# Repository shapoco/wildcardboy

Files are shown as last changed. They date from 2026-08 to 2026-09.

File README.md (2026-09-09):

# [WIP] WildCardBoy

Handheld Game Console with Replaceable MCU

## Concept

WildCardBoy is a handheld game console whose "brain" (MCU) can be swapped out.
It consists of two units:

- **Host shell**: The main unit with an LCD, keypad, TF card slot, and power supply.
  It has no game-execution capability of its own; instead, it has a slot for a logic card on its back.
- **Logic card**: A daughterboard that plugs into the slot. It carries the MCU that runs the game,
  along with the CPU peripheral circuitry of the target game console (e.g. TinyJoypad, Arduboy).

The differences between game consoles are confined to the logic card,
so supporting a new game console only requires building a new logic card.

The host shell acts as an RP2350B-based host controller with the following roles:

- Detecting the logic card and identifying its type via the on-card EEPROM (card profile)
- Reading keypad input and sending it to the logic card
- Driving the LCD based on drawing commands received from the logic card
- Flashing game programs stored on the TF card to the MCU on the logic card

For detailed specifications, see [spec/](spec/).

For demos and the latest development status, see the [#WildCardBoy tag on X](https://x.com/hashtag/WildCardBoy?f=live).

## Schematics

[host_shell.kicad_sch](https://kicanvas.org/?repo=https://github.com/shapoco/wildcardboy/blob/main/kicad/host_shell.kicad_sch)

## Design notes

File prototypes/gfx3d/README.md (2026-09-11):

# gfx3d プロトタイプ

WildCardBoy のシステムメニュー背景用 3D レンダリングライブラリのプロトタイプ。
仕様は [SPEC.md](SPEC.md) を参照。

## ディレクトリ構成

- `lib/include/shapoco/gfx3d/`: 公開ヘッダ (`gfx3d.hpp`, `math3d.hpp`)
- `lib/src/`: ライブラリ実装
- `example/common/`: サンプル共通のデモシーン (`scene.cpp`)
- `example/wasm/`: ブラウザ動作確認用サンプルの WASM ビルド環境
- `example/pretest/`: 実機 (pretest 試作機) での性能確認用ファームウェア。詳細は [example/pretest/README.md](example/pretest/README.md)
- `../../docs/prototypes/gfx3d/`: ビューアページ (index.html, main.js, gfx3d.wasm)

## ビルドと実行

Emscripten (emcc) が必要。

```sh
cd prototypes/gfx3d/example/wasm
make          # docs/prototypes/gfx3d/gfx3d.wasm を生成
make serve    # docs/ をルートに HTTP サーバを起動
```

ブラウザで http://localhost:8000/prototypes/gfx3d/ を開く。
(fetch を使用するため file:// では動作しない)

## コンパイルオプション

- `GFX3D_PERSPECTIVE_CORRECT_UV=1`: テクスチャ座標の透視補正を有効にする
  (デフォルトはアフィン補間。ピクセル単位の除算が追加される)

## メモリ使用量の目安

作業メモリはすべて `init()` に渡したアリーナから確保される。
サンプルは 128KB のアリーナを使用しており、内訳の目安は以下のとおり
(32bit 環境、`lib/src/gfx3d.cpp` の内部構造体のサイズに依存):

- ラインバケット: 画面の高さ x 4 バイト
- 線分プール: 残りの 1/4 (上限 512 個、1 個 64 バイト)
- トライアングルバッファ: 残り全部 (1 三角形約 124 バイト + インデックス 4 バイト。128KB のアリーナで約 770 個)

バッファがあふれた場合、超過分の三角形/線分はそのフレームでは破棄される。

## 制約

- テクスチャの幅・高さは 2 の冪であること (ラップをビットマスクで行うため。そうでない場合は繰り返しがずれる)
- ピクセル処理は固定小数点で、色は切り捨てで RGB565 に量子化される (float 実装との差は概ね 1 LSB 以内)

## 参考性能

480x320 のサンプルシーン (トーラス + キューブ 4 個、半透明・テクスチャ・環境マップ込み) を 1 フレーム:

- WASM (Node.js, シングルスレッド): 約 3 ms (固定小数化前は約 8 ms)
- RP2350 (312 MHz, シングルコア, `example/pretest`): 固定小数化前は render 約 55 ms (15〜18 fps)

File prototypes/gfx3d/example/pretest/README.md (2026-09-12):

# gfx3d pretest 実機サンプル

gfx3d プロトタイプの性能を実機で確認するためのファームウェア。
WASM サンプルと同じシーン ([../common/scene.cpp](../common/scene.cpp)) をホストシェルの LCD に描画する。

対象は **pretest の試作機** (ピン配置は [pretest/include/board_pins.hpp](../../../../pretest/include/board_pins.hpp) に従い、
[spec/](../../../../spec/) のピンアサインとは異なる)。ロジックカードは使用しない (LCIO / LCAUX / TF カードは触らない)。

## 構成

- pretest の足回りを無改造で流用: `board_pins.hpp` (ピン定義)、`sys_clock.cpp` (312 MHz)、
  `aux_i2c.cpp` (HAUX の PCA9555 キーパッド)、`lcd8080.pio` (8080 8bit 出力)
- `src/lcd_ili9488.cpp`: pretest の `ili9488.cpp` を元に、帯単位の非同期 DMA 転送 (`writeBytesAsync()`) を追加した LCD ドライバ
- `src/overlay.cpp`: 帯バッファへの文字描画 (LcdTap の 8x16 フォントをヘッダのみで使用)
- `src/main.cpp`: 描画ループ・計測・カメラ操作
- 全体を SRAM で実行する (`copy_to_ram`)。XIP キャッシュミスで計測値がぶれないようにするため

## 描画方式

480x320 を 32 ラインの帯 10 本に分けて `render()` する。帯バッファは 2 面 (各 30 KB) で、
帯 i を描画している間に帯 i-1 を DMA で LCD へ転送する (40 ns/byte、全画面で約 12.3 ms)。
LCD の TE 信号は試作機では MCU に接続されていないため、ティアリングは発生する。

## ビルド

Pico SDK 2.x と arm-none-eabi-gcc が必要。LcdTap サブモジュール (`submodule/lcdtap`) をチェックアウトしておくこと。
USB CDC 出力には SDK 側の TinyUSB サブモジュール (`$PICO_SDK_PATH/lib/tinyusb`) が必要
(無い場合は CMake が警告を出し、計測値は画面表示のみになる)。

```sh
./build.sh                                    # build/gfx3d_pretest.uf2
./build.sh -DGFX3D_PERSPECTIVE_CORRECT_UV=ON  # テクスチャ座標の透視補正を有効にする
./build.sh -DGFX3D_PERSPECTIVE_CORRECT_UV=OFF # 元に戻す (CMake キャッシュに残るため明示が必要)
```

## 操作

| キー | 動作 |
|---|---|
| 十字キー | カメラ回転 (左右 = yaw、上下 = pitch) |
| A / B | ズームイン / ズームアウト |
| X | カメラを初期位置に戻す |
| START | アニメーションの一時停止 / 再開 |
| SELECT | 画面左上の計測値表示の ON / OFF |

## 計測値

1 秒ごとに USB CDC (本体基板の native USB) へ以下を出力し、画面左上にも表示する。値は 1 フレームあたりの平均 (ms)。

```
[gfx3d] fps=... frame=...ms (max ...) key=... scene=... sort=... render=... (band max ...) swap=... lcdwait=... | cam ...
```

| 項目 | 内容 |
|---|---|
| `key` | キーパッド読み取り (I2C) |
| `scene` | `sceneBuild()` (座標変換・ライティング・投影、`beginScene()` 〜 `endScene()`) |
| `sort` | `beginRender()` (三角形の深度ソート) |
| `render` | 全帯の `render()` 合計。`band max` は 1 帯あたりの最大 |
| `swap` | 計測値の文字描画 + バイトスワップ |
| `lcdwait` | 前の帯の DMA 完了待ち + ウィンドウ設定 (描画が転送より速いと増える) |
| `tri` | 三角形数 (カリング後) / トライアングルバッファの容量。`drop` はあふれて破棄した数 |
| `span` | 1 ラインで同時に使用した線分数の最大 / 線分プールの容量。`drop` はあふれて破棄した数 |
| `arena` | 直近のフレームで実際に使用したアリーナのバイト数 (ラインバケット + 三角形 + 線分のピーク) / アリーナのサイズ |

画面の 3 行目は `tri` / `span` / `arena` (使用率 %) で、あふれが起きたときは数値の後ろに `!` が付く。

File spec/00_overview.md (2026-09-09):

# 概要

## コンセプト

MCU を差し替えることができるハンドヘルドゲームコンソール。
本体側のユニットを「ホストシェル」(host shell)、差し替え可能な子基板を「ロジックカード」(logic card) と呼ぶ。

- ホストシェルには ILI9488 互換 LCD とキーパッド (方向キー、ABXYボタンなど) を搭載。
- ホストシェルにはゲーム自体の実行機能は無く、背面にロジックカードを差し込むスロットがある。
- ロジックカードには頭脳となる MCU が搭載されており、ゲームプログラムはそこで実行される。
- ロジックカードには例えば Tinyjoypad や Arduboy のようなゲーム機の CPU 周辺回路が搭載される。
- 新しいゲーム機に対応するときは、ロジックカードだけを作ればよい。
- ホストシェルには TF カードスロットが搭載され、そこに格納されたゲームプログラムをロジックカード上の MCU に書き込むことができる。

## ホストシェル機能

ホストシェルは RP2350B をコアとして、システム全体を制御する「ホストコントローラ」を構成する。

- ロジックカードの検出
- PCA9555 を経由したキーパッド入力の取得
- ロジックカードへのキーパッド入力状態の送信
- ロジックカードからの LCD 描画命令の受信
- LCD 制御
- TF カード上のファイルシステムのブラウズ
- TF カードからバイナリファイルを読み込んでロジックカード上の MCU へのプログラム書き込み (SPI or USB)

## 回路図

[host_shell.kicad_sch](https://kicanvas.org/?repo=https://github.com/shapoco/wildcardboy/blob/main/kicad/host_shell.kicad_sch)

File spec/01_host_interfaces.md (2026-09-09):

# ホストシェルインタフェース

> **信号名について**: 回路図 (kicad/host_shell.kicad_sch) のネット名では、ホストシェル固有の信号に
> `HS` プレフィックスが付く (例: `HSLCD_D0`、`HSAUX_SDA`、`HSTF_CSX`)。本仕様書では従来どおり
> `H` プレフィックスで表記する。このほか回路図では、負論理信号に `X` サフィックスが付き (例: `HSLCD_RSTX`/`RDX`/`WRX`/`CSX`)、キー入力は `BTN_*` (例: `HKEY_L` → `BTN_L`)、TF カードと共有する SPI バスは `HSSPI_*` (`HTF_MISO/SCK/MOSI` → `HSSPI_MISO/SCK/MOSI`、`HTF_CS` → `HSTF_CSX`) と表記される。また `LCTF_ENAX` は回路図上では `LCTF_ENX` と表記される。

## キーパッド

ボタン類は全て PCA9555 (devaddr=0x21) 経由で読み取られる (電源ボタンを除く。後述「電源I/F」)。
Home ボタンはホストシェル側の機能の呼び出しに使用する。

|GPIO|割り当て|説明|
|---|---|---|
|GPIO36|HAUX_SDA|I2C データライン|
|GPIO37|HAUX_SCL|I2C クロックライン|

|PCA9555ポート|割り当て|説明|
|---|---|---|
|P0_0|HKEY_L|左キー|
|P0_1|HKEY_R|右キー|
|P0_2|HKEY_U|上キー|
|P0_3|HKEY_D|下キー|
|P0_4|HKEY_A|Aボタン|
|P0_5|HKEY_B|Bボタン|
|P0_6|HKEY_X|Xボタン|
|P0_7|HKEY_Y|Yボタン|
|P1_0|HKEY_SEL|SELECTボタン|
|P1_1|HKEY_STA|STARTボタン|
|P1_2|HKEY_BL|Lバンパー|
|P1_3|HKEY_BR|Rバンパー|
|P1_4|HKEY_HOME|Homeボタン|

PCA9555 の残りのポートは制御出力として使用する。

|PCA9555ポート|割り当て|説明|
|---|---|---|
|P1_5|EXTVIDENX|外部ビデオ回路イネーブル (負論理)|
|P1_6|LCVSYSEN|LCVSYS 給電イネーブル (High=給電)|
|P1_7|HLCD_SPIEN|LCD SPI モード切替 (High=SPI)|

- PCA9555 の全ポートは内部プルアップ (約 100kΩ) を持つため、電源投入直後 (全ポート入力状態) の
  上記制御信号は High 相当となる。
- HKEY_D (下キー) は 1kΩ + ショットキーダイオードを介して RP2350B の QSPI_SS にも接続されており、
  下キーを押しながら電源投入 / リセットすると USB ブートモード (BOOTSEL) に入る。
- HKEY_BL / HKEY_BR は基板外実装のスイッチ用コネクタ (J2/J3) に接続される。
- HAUX (GPIO36/37) と LCAUX (GPIO28/29) はどちらも RP2350B の I2C0 にのみ割り当て可能なため、
  ファームウェアはピン機能を切り替えて時分割で使用する。
- HAUX バスには PCA9555 (0x21) のほか RTC (RV-3028-C7、0x52) が接続される (後述「RTC」)。

## LCD I/F

ILI9488 互換の 320x480 ドットの液晶を横に倒して使用する。通常は 8bit パラレル (8080) 接続。
D0-7 は HSTX 対応端子 (GPIO12-19) に割り当てており、将来的に外付け回路による DVI-D / NTSC
出力を試せるよう外部コネクタ (J5) にも引き出している (後述「外部ビデオ出力」)。

|GPIO|割り当て|説明|
|---|---|---|
|GPIO12-19|HLCD_D0-D7|データバス (HSTX 対応端子)|
|GPIO20|HLCD_DC|SPI モードではマルチプレクサでパネルから切り離される|
|GPIO23|HLCD_RST||
|GPIO24|HLCD_RD||
|GPIO25|HLCD_WR|SPI モード (4 線) では D/C として使用|
|GPIO26|HLCD_CS||
|GPIO27|HLCD_VSYNC|パネルの TE 出力 (ホスト側は入力)|
|GPIO46|HLCD_BL|バックライト PWM (High=点灯)|

### SPI モード

HLCD_SPIEN (PCA9555 P1_7) を High にするとパネルのインタフェースストラップが SPI に切り替わり、
パネルの DC/SCL 端子にはアナログマルチプレクサ (SN74LVC1G3157) 経由で HTF_SCK (GPIO34) が
接続される。シリアルデータは HTF_MOSI (GPIO35)。すなわち TF カードと SPI バスを共有する
(CS は HLCD_CS で独立)。4 線 SPI の D/C にはパネルの WR 端子 (HLCD_WR) を使用する。
パネルの SDO は接続していない (書き込み専用)。
HLCD_SPIEN 切り替え後は HLCD_RST でパネルをリセットすること。
D0-7 を外部ビデオ回路が使用している間、本体 LCD はこのモードで制御する。

### 外部ビデオ出力

HLCD_D0-7、HLCD_DC/RST/RD/WR/CS、VSYS、3.3V を外部コネクタ (J5) に引き出している。
EXTVIDENX (PCA9555 P1_5、負論理) で外部回路をイネーブルする。
DVI-D 出力時は D0-7 (HSTX) を 4 差動ペアとして使用する想定 (信号は外部回路側でバッファする)。

## TF カード I/F

SPI 接続。

|GPIO|割り当て|説明|
|---|---|---|
|GPIO32|HTF_MISO||
|GPIO33|HTF_CS||
|GPIO34|HTF_SCK||
|GPIO35|HTF_MOSI||
|GPIO42|HTF_DETX|カード検出。Low=挿入 (基板上でプルアップ)|

- MISO/SCK/MOSI は LCD の SPI モードとバスを共有する (CS は別)。
- ロジックカードへの接続切り替え (LCTF_ENAX) は [02_wildcardbus.md](02_wildcardbus.md) を参照。

## オーディオ I/F

|GPIO|割り当て|説明|
|---|---|---|
|GPIO44|HAUDIO_L|PWM オーディオ出力 (左)|
|GPIO45|HAUDIO_R|PWM オーディオ出力 (右)|

- PWM 出力はシュミットトリガバッファで整形後、RC フィルタ (fc ≈ 7kHz) で平滑され、
  ロジックカードのオーディオ (LCAUDIO_L/R) と抵抗ミックスされる。
- ミックス後の信号は音量ボリュームを経てスピーカアンプ (LM4890 BTL x2) と
  ヘッドホンアンプ (LM4880) に入る。ヘッドホンジャックの挿入検出により
  スピーカ / ヘッドホンはハードウェアで自動的に切り替わる (GPIO 制御不要)。

## 電源I/F

電源系統: VBUS (USB) と VBAT (Li-Po) をダイオード OR した電源を、電源ボタン付きロードスイッチ
(XC6194) を通して VSYS とし、昇降圧 DCDC (TPS63802) で 3.3V を生成する。
充電は MCP73831 (約 370mA)。
電源ボタンのクリックは GPIO41 (BTN_PWRX) で検知し、ファームウェアが後始末をしてから
SYSSD で自己遮断する (安全なシャットダウン)。長押しは XC6194 のハードウェア機能による
強制電源断で、ファームウェアが暴走していても機能する。

|GPIO|信号名|説明|
|---|---|---|
|GPIO39|SYSSD|High でシステム電源断 (XC6194 SHDN)|
|GPIO41 (ADC1)|BTN_PWRX|電源ボタン検知 (Low=押下)。3.3V に 100kΩ でプルアップし、ショットキーダイオード経由で BTN_PWRX ノード (VCOM 系、最大約 4.2V) から絶縁|
|GPIO43 (ADC3)|ADCBAT|バッテリー電圧監視 (VBAT の 1/2 分圧。システム OFF 中は分圧回路ごと切り離される)|

- 電源ボタンで電源 ON した直後はボタンが押されたままのため BTN_PWRX は Low で起動する。
  ファームウェアは一度 High (離した状態) を確認してからクリック検知を有効にすること。
  チャタリング除去もソフトウェアで行う (BTN_PWRX ノードにコンデンサはない)。

ロジックカードへの電源供給:

|電源|制御|説明|
|---|---|---|
|LC3V3|なし|ホストシェル動作中は常時給電|
|LCVSYS|LCVSYSEN (PCA9555 P1_6)|High で給電。ソフトスタート付き|

## RTC

RV-3028-C7 (I2C devaddr=0x52) を HAUX バス (GPIO36/37) に接続している。

|項目|内容|
|---|---|
|VDD|3.3V|
|VBACKUP|VBAT (ヒューズ F2 の下流)。システム OFF 中もバッテリーから時刻保持 (約 45nA)|
|INT|未使用 (テストポイントのみ)。アラームフラグは I2C ポーリングで読む|
|CLKOUT|未使用 (テストポイントのみ)|
|EVI|10kΩ プルダウン (未使用)|

ファームウェアでの初期化時の注意:

- バックアップ切替 (BSM) は POR デフォルトで無効。EEPROM 設定で DSM または LSM を
  一度書き込むこと (EEPROM 保持のため以後は不要)。
- トリクル充電は無効のまま使用する (VBACKUP が Li-Po 直結のため)。
- CLKOUT はデフォルトで 32.768kHz を常時出力するため、無効化して消費電流と輻射を抑える。
- devaddr 0x52 は Xiamocon カードのバッテリー監視 ADC (ADC101C027) と同値だが、
  あちらはカード側バス ([04_host_controller.md](04_host_controller.md) 参照) 上の
  エミュレーションであり、バスが異なるため衝突しない。

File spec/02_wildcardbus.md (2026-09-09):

# ロジックカード I/F (WildCardBus)

2x12 ピンのピンソケット。

|ヘッダピン番号|GPIO|信号名|説明|
|---|---|---|---|
|1|-|LCAUDIO_L|オーディオ左チャンネル|
|2|-|LCAUDIO_R|オーディオ右チャンネル|
|3|-|GND|グランド|
|4|GPIO40 (ADC0)|LCA0|アナログ入力 (ホストシェルの ADC に接続)|
|5|GPIO0|LCIO0|ロジックカード側の GPIO0|
|6|GPIO1|LCIO1|ロジックカード側の GPIO1|
|7|GPIO2|LCIO2|ロジックカード側の GPIO2|
|8|GPIO3|LCIO3|ロジックカード側の GPIO3|
|9|GPIO4|LCIO4|ロジックカード側の GPIO4|
|10|GPIO5|LCIO5|ロジックカード側の GPIO5|
|11|GPIO6|LCIO6|ロジックカード側の GPIO6|
|12|GPIO7|LCIO7|ロジックカード側の GPIO7|
|13|GPIO8|LCIO8|ロジックカード側の GPIO8|
|14|GPIO9|LCIO9|ロジックカード側の GPIO9|
|15|GPIO10|LCIO10|ロジックカード側の GPIO10|
|16|GPIO11|LCIO11|ロジックカード側の GPIO11|
|17|GPIO21|LCIO12|ロジックカード側の GPIO12|
|18|GPIO22|LCIO13|ロジックカード側の GPIO13|
|19|GPIO28|LCAUX_SDA|I2C データライン|
|20|GPIO29|LCAUX_SCL|I2C クロックライン|
|21|GPIO30|LCUSB_DP|USB D+|
|22|GPIO31|LCUSB_DM|USB D-|
|23|-|LC3V3|3.3V 電源 (常時給電)|
|24|-|LCVSYS|VBUS/VBAT の OR 電源 (スイッチ付き)|

- GPIO 列はホストシェル (RP2350B) 側の GPIO 番号。LCIO12/13 は HSTX 端子確保のため
  ホスト側 GPIO21/22 に割り当てられている (信号名・機能は従来どおり)。
- LC3V3 はホストシェル動作中は常時給電される (イネーブル制御なし)。
- LCVSYS は VBUS と VBAT のダイオード OR 出力 (約 3.0〜5.0V) で、ホストシェルが給電を
  ON/OFF する (ソフトスタート付き)。安定した 5V を必要とするカードはカード側で昇圧すること。

## LCD I/F が I2C の場合

|信号名|割り当て|
|---|---|
|LCIO2|LCLCD_SDA|
|LCIO3|LCLCD_SCL|

## LCD I/F が SPI の場合

|信号名|割り当て|
|---|---|
|LCIO0|LCLCD_RST|
|LCIO1|LCLCD_CS|
|LCIO2|LCLCD_SCK|
|LCIO3|LCLCD_MOSI|
|LCIO4|LCLCD_DC|

## LCD I/F が 8bit パラレルの場合

|信号名|割り当て|
|---|---|
|LCIO0|LCLCD_RST|
|LCIO1|LCLCD_CS|
|LCIO2|LCLCD_WR|
|LCIO3|LCLCD_D0|
|LCIO4|LCLCD_D1|
|LCIO5|LCLCD_D2|
|LCIO6|LCLCD_D3|
|LCIO7|LCLCD_D4|
|LCIO8|LCLCD_D5|
|LCIO9|LCLCD_D6|
|LCIO10|LCLCD_D7|
|LCIO11|LCLCD_DC|

## LCD VSYNC 出力

ロジックカード上の MCU が LCD からの同期信号 (ST7789 の TE 信号など) の入力を要求する場合は、
ホストシェルが生成する自走パルスをロジックカードへ供給する (物理 LCD とは同期しない。
[04_host_controller.md](04_host_controller.md))。
割り当ては固定ではなく、カードプロファイルで機能番号 3 のポートとして空いている任意の LCIO に
割り当てる ([03_card_profile.md](03_card_profile.md))。LCD I/F が SPI のカードでは LCIO5 を推奨する。

## キーパッド I/F がパラレルの場合

ロジックカード側の LCD I/F がパラレル以外の場合で、TF カード I/F を持たず、使用するキーが方向キーと A、B、START、SELECT のみの場合は、キーパッド I/F はパラレル接続となる。

|信号名|割り当て|説明|
|---|---|---|
|LCIO5|LCKEY_L|左キー|
|LCIO6|LCKEY_R|右キー|
|LCIO7|LCKEY_U|上キー|
|LCIO8|LCKEY_D|下キー|
|LCIO9|LCKEY_A|Aボタン|
|LCIO10|LCKEY_B|Bボタン|
|LCIO11|LCKEY_STA|STARTボタン|
|LCIO12|LCKEY_SEL|SELECTボタン|

## キーパッド I/F が I2C の場合

キーパッド I/F がパラレルで使用できない場合は I2C 接続となる。I2C は LCAUX_SDA/LCAUX_SCL を通じてロジックカード上の PCA9555 (devaddr=0x20) に接続される。

|PCA9555ポート|割り当て|説明|
|---|---|---|
|P0_0|LCKEY_L|左キー|
|P0_1|LCKEY_R|右キー|
|P0_2|LCKEY_U|上キー|
|P0_3|LCKEY_D|下キー|
|P0_4|LCKEY_A|Aボタン|
|P0_5|LCKEY_B|Bボタン|
|P0_6|LCKEY_X|Xボタン|
|P0_7|LCKEY_Y|Yボタン|
|P1_0|LCKEY_STA|STARTボタン|
|P1_1|LCKEY_SEL|SELECTボタン|
|P1_2|LCKEY_BL|Lバンパー|
|P1_3|LCKEY_BR|Rバンパー|

## キーパッド I/F が仮想 I/O エキスパンダの場合

カードプロファイルの `lcio.useVirtIoExp` が true の場合、ホストコントローラ自身が I2C スレーブとなり、
ロジックカード上の I/O エキスパンダ IC の動作を模擬する (詳細は [03_card_profile.md](03_card_profile.md) および [04_host_controller.md](04_host_controller.md))。
ロジックカード上の MCU は、実チップに対するのと同様に I2C マスタとしてホストへアクセスする。
キーパッド状態のほか、カードによってはディスプレイリセット等の信号もこの経路で受け渡す ([03_card_profile.md](03_card_profile.md))。

|信号名|割り当て|
|---|---|
|LCIO6|LCVIO_SDA|
|LCIO7|LCVIO_SCL|

- ホスト側では GPIO6/7 を I2C1 (スレーブモード) として使用する。
- バスのプルアップ抵抗はロジックカード側に実装する (4.7kΩ 推奨)。
- I2C1 ペリフェラルは LCD I/F が I2C の場合の受信にも使用するため、仮想 I/O エキスパンダと I2C LCD は併用できない。
  また LCIO6/7 は 8bit パラレル LCD (D3/D4) およびパラレルキーパッド (LCKEY_R/U) と衝突する。
  実質的に、仮想 I/O エキスパンダは LCD I/F が SPI のカード専用である。

## TF カード I/F

ロジックカード側が TF カード I/F を要求する場合は、ホストシェル側の TF カードスロットがロジックカードへ接続される。

|信号名|割り当て|
|---|---|
|LCIO8|LCTF_MOSI|
|LCIO9|LCTF_CS|
|LCIO10|LCTF_SCK|
|LCIO11|LCTF_MISO|

ロジックカードが TF カードを占有する間、ホストコントローラは TF カードへはアクセスできなくなる。
TF カードスロットをホストコントローラに接続するかロジックカードに接続するかは、ホストコントローラの GPIO で切り替える。

|GPIO|信号名|説明|
|---|---|---|
|GPIO38|LCTF_ENAX|Low=TFカードはロジックカードに接続, High=TFカードはホストコントローラに接続|

LCTF_ENAX は基板上でプルアップされている。
LCTF_ENAX が Low の間は、ホストコントローラ側の TF カード I/F は High-Z でなければならない。

## USB I/F

USB I/F は、将来的にホストコントローラが USB ホストとなってロジックカード上の USB デバイスと通信するために使用される。
ロジックカード上の MCU が RP2040 や RP2350 で、ホストから UF2 を書き込むようなシーンが想定される。

## アナログ入力 (LCA0)

ロジックカードからホストシェルへのアナログ信号。ホストシェルは GPIO40 (ADC0) で読み取る。

第一の用途はロジックカードからの LCD バックライト輝度制御で、カード側で PWM を RC フィルタで
平滑して LCA0 に出力し、ホストシェルが ADC 値をバックライト PWM (HLCD_BL) に反映する。
使用しないカードは未接続でよい。

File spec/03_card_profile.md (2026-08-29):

# カードプロファイルチップ

LCAUX_SDA/SCL は、ロジックカード上の EEPROM (24LC256, devaddr=0x50) に接続されており、ホストシェル側から読み出すことで、ロジックカードの種類を判別することができる。

## EEPROM レイアウト

内容は先頭から次の通り。

1. CBOR オブジェクトの長さ (4 バイト, Big Endian)
2. CBOR オブジェクト
3. 長さ + CBOR オブジェクトに対する 32bit CRC32 チェックサム (Big Endian)

## CBOR オブジェクト

CBOR オブジェクトの内容は次の通り。

```json
{
  "format": "WCBCARD", // 固定値
  "id": "<カードID>", // 最大 16 バイト (ヌル終端除く)
  "name": "<カード名>", // 最大 64 バイト (ヌル終端除く)

  // ロジックカードの汎用 I/O の設定
  "lcio": {
    "useTfCard": <false|true>, // TF カード I/F を使用する場合は true。省略時は false。
    "useVirtIoExp": <false|true>, // 仮想 I/O エキスパンダを使用する場合は true。省略時は false。
    "ports": [
      {
        "i": <LCIO番号>,
        "f": <機能番号>,
        "m": <モード番号>
      },
      ...
    ]
  },

  // 仮想 I/O エキスパンダの設定 (lcio.useVirtIoExp が true の場合)
  "virtIoExp": {
    "chip": "<チップID>", // "mcp23017" または "pca9555"
    "addr": <I2Cスレーブアドレス> // 例: MCP23017 は通常 32 (0x20)、PCA9555 (Xiamocon) は 34 (0x22)
  },

  // ロジックカードの LCD I/F の設定
  "lcdtap": {
    "preset": "<LcdTap のプリセット名>",
    "cfg": { // プリセットから変更する場合
      (LcdTap の設定を CBOR 化したもの)
    }
  },

  // LCD VSYNC 出力の設定 (機能番号 3 のポートを持つ場合。省略可)
  "vsync": {
    "hz": <パルス周波数>, // Hz。省略時 60
    "pulseUs": <パルス幅> // マイクロ秒。省略時 1000
  },

  // ロジックカード上の MCU へのプログラム書き込みに使用する ISP プロトコル
  "isp": {
    "mcu": "<MCU ID>", // 最大 16 バイト (ヌル終端除く)
    "method": <ISPプロトコル番号>,
    "ports": [ // LCIO を使って書き込みを行う場合
      {
        "i": <LCIO番号>,
        "f": <機能番号>,
        "m": <モード番号>
      },
      ...
    ]
  },

  // ホストシェル側ボタンとロジックカード側ボタンの対応関係
  "keymap": {
    "map": [
      {
        "s": <物理ボタン番号>,
        "d": <割当先ボタン番号>
      },
      ...
    ]
  }
}
```

## LCIO 番号

LCIO 番号は次の通り。

|LCIO番号|信号名|
|---|---|
|0-13|LCIO0-13|
|32-39|PCA9555 の P0_0-P0_7 (I2C 経由)|
|40-47|PCA9555 の P1_0-P1_7 (I2C 経由)|
|64-71|仮想 I/O エキスパンダのポート A (MCP23017: GPA0-7、PCA9555: P0_0-P0_7)|
|72-79|仮想 I/O エキスパンダのポート B (MCP23017: GPB0-7、PCA9555: P1_0-P1_7)|

LCIO32-47 はロジックカード上の PCA9555 (devaddr=0x20, LCAUX 経由) のポートであり、モードは `OUTPUT` または `OPEN_DRAIN` (+ `負論理`) を使用できる。
オープンドレイン出力は PCA9555 の CONFIG レジスタによる入出力切替 (アサート = 出力 Low、解放 = 入力) で実現する。
プルアップ/プルダウンの指定は無視される (入力時は PCA9555 内蔵の弱いプルアップ)。

LCIO64-79 は `lcio.useVirtIoExp` が true の場合に有効な仮想ポートであり、主にキーパッド状態の受け渡しに使用する
([02_wildcardbus.md](02_wildcardbus.md)、[04_host_controller.md](04_host_controller.md))。
キー (機能番号 16-27) のモードは `OPEN_DRAIN` + `負論理` を使用する (実チップのプルアップ入力 + アクティブ Low に相当)。
プルアップ/プルダウンの指定は無視される。

仮想ポートに機能番号 1 (LCD I/F) を割り当てた場合、そのポートはディスプレイリセット (LCLCD_RST 相当) を意味する。
モードは `入力` + `負論理` (m=33) とし、カード側 MCU がそのビットをエキスパンダの出力に設定して Low を駆動している間、
ホストは LCD をリセット状態として扱う ([04_host_controller.md](04_host_controller.md))。
ホスト実装は当面このポートを無視してよい (段階的対応。その場合の LCD リセットは、カードが送る
初期化コマンド列への追従に依存する)。

## ポートの機能番号

ポートの機能番号は次の通り。

|機能番号|機能|
|---|---|
|0|未使用|
|1|LCD I/F|
|2|TF カード I/F|
|3|LCD VSYNC 出力|
|16|左ボタン|
|17|右ボタン|
|18|上ボタン|
|19|下ボタン|
|20|Aボタン|
|21|Bボタン|
|22|Xボタン|
|23|Yボタン|
|24|STARTボタン|
|25|SELECTボタン|
|26|Lバンパー|
|27|Rバンパー|
|32|RESET|
|33|BOOTSEL|
|34|ISP (CS)|
|35|ISP (SCK)|
|36|ISP (MOSI)|
|37|ISP (MISO)|
|38|ISP (UART TX)|
|39|ISP (UART RX)|
|48|I2C スレーブ|

## ポートのモード番号

ポートのモード番号は次の値を足したもの。

|モード番号|モード|
|---|---|
|0|未使用|
|1|入力|
|2|出力|
|4|オープンドレイン出力|
|8|プルアップ|
|16|プルダウン|
|32|負論理|

## ISP プロトコル番号

ISP プロトコル番号は次の通り。

|ISPプロトコル番号|プロトコル|
|---|---|
|0|未使用|
|1|SPI|
|2|UART (Espressif シリアルブートローダ)|
|16|USB (Mass Storage Class)|

## MCU ID

|ID|MCU|
|---|---|
|attiny85|ATtiny85|
|atmega32u4|ATmega32U4|
|esp8266|ESP8266|
|rp2040|Raspberry Pi Pico|
|rp2350|Raspberry Pi Pico 2|

## キーマップのボタン番号

キーマップのボタン番号は次の通り。

|ボタン番号|ボタン|
|---|---|
|0|左ボタン|
|1|右ボタン|
|2|上ボタン|
|3|下ボタン|
|4|Aボタン|
|5|Bボタン|
|6|Xボタン|
|7|Yボタン|
|8|STARTボタン|
|9|SELECTボタン|
|10|Lバンパー|
|11|Rバンパー|

## 解釈の規則

LCIO のポート設定と LcdTap/ISP の設定が衝突する場合は後者を優先する。

`isp.method` が 16 (USB) の場合、`isp.ports` (または `lcio.ports`) に RESET (32) と BOOTSEL (33) のポートが必要である。
`isp.method` が 2 (UART) の場合、`isp.ports` に ISP (UART TX) (38) と ISP (UART RX) (39) のポートが、
`isp.ports` (または `lcio.ports`) に RESET (32) と BOOTSEL (33) のポートが必要である。
UART には任意の LCIO を割り当てられるが、LCIO10 (TX) / LCIO11 (RX) を推奨する (ホスト側でハードウェア UART1 を使用できる)。
`lcio.useVirtIoExp` が true の場合、`virtIoExp` メンバが必要であり、LCIO6/7 に機能番号 48 (I2C スレーブ) のポートを記述する。
仮想 I/O エキスパンダは LCD I/F が SPI のカードでのみ使用できる ([02_wildcardbus.md](02_wildcardbus.md))。
`lcio.useTfCard` が true のロジックカードは、動作中に TF カードを占有する (LCTF_ENAX=Low)。

キーマップのボタン番号 `d` と LCIO の機能番号 `f` は `f = 16 + d` の関係にある。
キーマップに現れないホストシェル側ボタンは、ロジックカードへは送られない。
複数の物理ボタンを同一の割当先 `d` に割り当ててもよい (いずれかが押されていればアサートされる。
例: Xiamocon のファンクションスイッチに L/R バンパーの両方を割り当てる)。

機能番号 1 (LCD I/F) および 2 (TF カード I/F) を持つポートは、当該 I/F が占有することを示すだけであり、
各信号 (SDA/SCL、MOSI/MISO/SCK/CS など) の LCIO への割り当ては [WildCardBus](02_wildcardbus.md) の固定表に従う (PIO や物理配線の都合で自由には選べない)。
キーパッド I/F が I2C の場合の割り当ても同様に [WildCardBus](02_wildcardbus.md) の固定表に従う。
`lcio.ports` に現れない LCIO は未使用 (High-Z) とする。

機能番号 3 (LCD VSYNC 出力) のポートは LCIO0-13 にのみ、高々 1 つ割り当てることができる。
モードは `出力` とする (`負論理` でパルス極性を反転できる)。
ホストシェルはカード動作中、このポートに `vsync` メンバで指定された自走パルスを PWM で出力する
([02_wildcardbus.md](02_wildcardbus.md)、[04_host_controller.md](04_host_controller.md))。
`vsync` メンバは省略可能で、`hz` (パルス周波数 [Hz]、20〜1000、省略時 60) と
`pulseUs` (パルス幅 [µs]、1 以上かつ周期未満、省略時 1000) を持つ。
機能番号 3 のポートが無い場合、`vsync` メンバは無視される。

`lcdtap.cfg` は、LcdTap の `CONFIG_IDS` (`ctrlFamily`, `busInterface`, `i2cAddr`, `buffWidth`, ... `scaleMode`) をキー、
`setConfigValueById()` に渡す int16 値を値とするマップで、プリセットを適用した後に上書きされる
(LcdTap の JSON I/F `setparams` と同じ語彙)。`dviWidth`/`dviHeight` はホスト側で決定するため対象外。

## 符号化の制約

CBOR の符号化は次の制約に従う (ホスト側パーサの簡略化のため)。

- definite length のみ (indefinite length は不使用)
- 整数は CBOR の非負整数 (major type 0) と負整数 (major type 1) のみ (`lcdtap.cfg` の `intfFmtOvr` は -1 = Off)。真偽値は major type 7 の `true` / `false` (`useTfCard`)。浮動小数点・タグ・バイト列は不使用
- マップのキーは text string
- `id` / `name` の長さ制限は UTF-8 バイト数で数える

CRC32 は zlib 互換の CRC-32 (多項式 0x04C11DB7 反転形 0xEDB88320、初期値 0xFFFFFFFF、最終 XOR 0xFFFFFFFF) とする。
CBOR オブジェクトは高々数 kB を想定しており、ホストは全体を SRAM に読み込んで CRC を検証した後にパースする。

サンプル: [cards/TinyJoypad/profile.json](../cards/TinyJoypad/profile.json)。編集ツール: [docs/profile-editor](../docs/profile-editor/)。

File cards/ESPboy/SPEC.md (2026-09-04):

# ESPboy カード

ESPboy カードは、ESP8266 を搭載した小型ゲーム機「ESPboy」(ESPboy2) の CPU 周辺回路を WildCardBoy のロジックカードとして実装したもの。
ESPboy 用のアプリバイナリ (Arduino ビルドの .bin) をそのまま実行することを目標とする。

## カードID

`ESPboy`

## 電源

LC3V3 (ホストシェルの 3.3V) を ESP8266 へ直接供給する。LDO は搭載しない。LCVSYS は使用しない。

## カード I/F

ESP8266 (ESP-12F / WeMos D1 mini 相当、Flash 4MB) と WildCardBus の接続:

|信号名|ESP8266 割り当て|説明|
|---|---|---|
|LCAUDIO_L|GPIO0|サウンド出力 (RC フィルタ + カップリングコンデンサ経由)|
|LCAUDIO_R|GPIO0|同上|
|LCIO0|未接続|LCLCD_RST は使用しない|
|LCIO1|GND|LCLCD_CS (常時アサート。ESPboy は LCD の CS を MCP23017 経由で制御するため、カード上に物理 CS 信号が無い)|
|LCIO2|GPIO14 (HSPI SCK)|LCLCD_SCK|
|LCIO3|GPIO13 (HSPI MOSI)|LCLCD_MOSI|
|LCIO4|GPIO16|LCLCD_DC|
|LCIO6|GPIO4|LCVIO_SDA|
|LCIO7|GPIO5|LCVIO_SCL|
|LCIO10|GPIO3 (RXD0)|ISP UART TX (ホスト → ESP8266)|
|LCIO11|GPIO1 (TXD0)|ISP UART RX (ESP8266 → ホスト)|
|LCIO12|GPIO0|BOOTSEL (open-drain、負論理)|
|LCIO13|RST|RESET (open-drain、負論理)|

GPIO0 はブートモード選択 (BOOTSEL) とサウンド出力を兼ねる (ESPboy の仕様)。
動作中のホスト側 LCIO12 は High-Z とし、サウンド出力の負荷にならないようにする。

## カード上の抵抗

|箇所|値|備考|
|---|---|---|
|LCVIO_SDA/SCL プルアップ|4.7kΩ x2|I2C バス|
|RST プルアップ|10kΩ||
|EN (CH_PD) プルアップ|10kΩ||
|GPIO0 プルアップ|10kΩ|ブートストラップ|
|GPIO2 プルアップ|10kΩ|ブートストラップ (NeoPixel は実装しない)|
|GPIO15 プルダウン|10kΩ|ブートストラップ|
|GPIO3 (RXD0) プルアップ|10kΩ|ホスト側 High-Z 時のフロート防止|

## 仮想 I/O エキスパンダ

ESPboy は MCP23017 (devaddr=0x20) をボタン入力・TFT CS・LED LOCK に使用する。
カードには実チップを搭載せず、ホストコントローラが模擬する ([spec/04_host_controller.md](../../spec/04_host_controller.md))。

|MCP23017ポート|LCIO|割り当て|
|---|---|---|
|GPA0|LCIO64|LEFT (左キー)|
|GPA1|LCIO65|UP (上キー)|
|GPA2|LCIO66|DOWN (下キー)|
|GPA3|LCIO67|RIGHT (右キー)|
|GPA4|LCIO68|ACT (Aボタン)|
|GPA5|LCIO69|ESC (Bボタン)|
|GPA6|LCIO70|LFT (Lバンパー)|
|GPA7|LCIO71|RGT (Rバンパー)|
|GPB0|(未使用)|TFT CS (アプリが出力設定する。ホストは使用しない)|
|GPB1|(未使用)|LED LOCK (同上)|

ESPboy 実機で同一バス上にある MCP4725 (バックライト調光 DAC、devaddr=0x60) は模擬しない
(ESPboy ライブラリは初期化時の probe が NACK になると DAC を無効化したまま動作する)。
NeoPixel (GPIO2) も実装しない。

## EEPROM

[profile.json](profile.json) を参照 (生成済みイメージ: [profile.hex](profile.hex))。

## プログラミング

LCIO10-13 を使用し、UART 経由 (Espressif シリアルブートローダプロトコル) で ESP8266 の SPI Flash に書き込む
([spec/04_host_controller.md](../../spec/04_host_controller.md))。
アプリバイナリは Flash オフセット 0x0000 に書き込む単一の .bin ファイルとする。

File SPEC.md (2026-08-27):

# WildCardBoy 仕様

仕様は `spec/` 配下に分割して置いている。

| ファイル | 内容 |
|---|---|
| [spec/00_overview.md](spec/00_overview.md) | コンセプト、ホストシェル機能 |
| [spec/01_host_interfaces.md](spec/01_host_interfaces.md) | ホストシェル側インタフェース (キーパッド、LCD、TF カード、オーディオ、電源) |
| [spec/02_wildcardbus.md](spec/02_wildcardbus.md) | ロジックカード I/F (WildCardBus) のピン配置と各 I/F の固定割り当て |
| [spec/03_card_profile.md](spec/03_card_profile.md) | カードプロファイルチップ (EEPROM) の内容 |
| [spec/04_host_controller.md](spec/04_host_controller.md) | ホストコントローラの動作 (起動、システムメニュー、ファイルブラウザ、ゲームモード) |
| [spec/05_tf_card.md](spec/05_tf_card.md) | TF カードのディレクトリ構成 |

カード毎の仕様は [cards/](cards/) 配下の各サブディレクトリ (`SPEC.md`、`profile.json`、`profile.hex`) に置いている。

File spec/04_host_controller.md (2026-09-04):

# ホストコントローラ

## 起動

起動時、ロジックカードの EEPROM からカードプロファイルを読み出し、カードの種類を判別する。
カードプロファイルに応じて、ロジックカードの LCD I/F、キーパッド I/F、TF カード I/F の接続方法を切り替える。
ロジックカードを検出できなかった場合は「システムメニュー」を起動する。

## システムメニュー

起動時は「システムメニュー」が動作する。

メニューの階層構造:

- ホーム画面
  - `Start card` / `Stop card`: ロジックカードを起動 / 停止する (状態に応じてどちらか一方が表示される。後述「ロジックカードの状態」)
  - `Apps`:
    - <ファイルブラウザ>: TF カードの `WCB/Cards/<カードID>/Apps/` からバイナリファイルを選択後、ロジックカード上の MCU に書き込む。
      書き込みはロジックカード停止中に行い、完了後にロジックカードを起動するかどうかをユーザに確認する。
  - `Profile`:
    - <ファイルブラウザ>: TF カードの `WCB/Cards/` からカードプロファイル (`profile.hex`) を選択後、ロジックカードのカードプロファイルチップに書き込む。
      書き込み後はロジックカードの検出をやり直す。

ロジックカードが TF カードを占有している間 (動作中かつ `useTfCard`) は、`Apps` / `Profile` は使用できない (先に停止する)。

## ファイルブラウザ

システムメニューから呼び出す形で、TF カード上のファイルシステムをブラウズすることができる。
Windows の「開く」ダイアログのイメージ。

LCTF_ENAX=High にした上で HTF_xxxx 端子を使って TF カードにアクセスする。
ロジックカードが TF カードを占有している間は、ホストコントローラは TF カードにアクセスできない。

画面の一番上に現在のディレクトリパスを表示し、その下にディレクトリ内のファイル/ディレクトリをリスト表示する。

上下キーで選択カーソルを移動。
左キーで親ディレクトリに移動。
右キーで選択された子ディレクトリに移動。
B キーで親ディレクトリに移動。
ファイル選択が要求されているときに子ディレクトリを選択して A キー: 子ディレクトリに移動する。
フォルダ選択が要求されているときにファイルを選択して A キー: 無視
要求された種類の項目が選択された状態で A キー: 当該項目を開くかどうかの確認ダイアログを表示し、A キーで開く、B キーでキャンセル。

画面一番下に操作説明を表示:

```
U/D:Select  L:Parent  R:Child  A:Open  B:Cancel
```

## ロジックカードの状態

ロジックカードには「停止」と「動作」の 2 状態がある。

|状態|RESET|LCTF_ENAX|説明|
|---|---|---|---|
|停止|アサート|High|ロジックカード上の MCU はリセット状態。ホストシェルは TF カードにアクセスできる。将来的にはロジックカードへの LCVSYS 供給 (LCVSYSEN) もここで停止する|
|動作|デアサート|`useTfCard` なら Low、それ以外は High|ゲームモード。`useTfCard` の場合、ホストシェル側の HTF_xxxx 端子は High-Z にし、ホストシェルから TF カードにはアクセスしない|

- ホストシェル起動時に既にロジックカードが挿さっていた場合は、プロファイル検出後に自動的に「動作」へ移行する。
- ホストシェル起動後にロジックカードが挿された場合、およびアプリ書き込みの完了後は「停止」のままとし、ロジックカードを起動するかどうかをユーザに確認する (A: 起動 / B: 停止のまま)。
- システムメニューの `Start card` / `Stop card` で状態を切り替える。
- アプリ書き込み (ISP) の間は、ISP プロトコルが要求するとおりに RESET / BOOTSEL を操作する。

### USB (MSC) によるアプリ書き込み

`isp.method` = 16 のロジックカード (RP2040 / RP2350 など) では、次の手順で UF2 ファイルを書き込む。

1. 停止状態 (RESET アサート) から BOOTSEL をアサートし、RESET をデアサートして MCU を起動、その後 BOOTSEL をデアサートする。
2. ホストコントローラが USB ホスト (LCUSB_DP/DM) として MCU の USB MSC デバイスをマウントする。
3. UF2 ファイルの各 512 バイトブロックを MSC デバイスに書き込む。
4. MCU はすべてのブロックを受け取ると Flash への書き込みを終えて再起動し、USB から切断される。ホストコントローラはこの切断をもって書き込み完了とみなす (タイムアウトあり)。
5. RESET をアサートして停止状態に戻す。

### UART によるアプリ書き込み

`isp.method` = 2 のロジックカード (ESP8266 など) では、UART 経由で Espressif シリアルブートローダプロトコル (SLIP フレーミング) により書き込む。
ホスト側の実装には Espressif 公式の esp-serial-flasher の移植を想定する。

1. 停止状態 (RESET アサート) から BOOTSEL (ESP8266 の GPIO0) をアサートし、RESET をデアサートして MCU を UART ダウンロードモードで起動する。その後 BOOTSEL をデアサートする。
2. 115200 bps で SYNC を行い、スタブローダを RAM へ転送・起動してボーレートを 921600 bps へ切り替える。
3. バイナリファイルを Flash オフセット 0x0000 から書き込む (圧縮転送)。書き込み後、MD5 コマンドで検証する。
4. RESET をアサートして停止状態に戻す。

UART TX/RX のホスト側ポートは書き込み中のみ駆動し、それ以外の期間は High-Z とする
(ESP8266 の RXD0 が浮かないよう、ロジックカード側にプルアップを実装すること)。

## 仮想 I/O エキスパンダ

`lcio.useVirtIoExp` が true のロジックカードでは、ホストコントローラは GPIO6/7 (LCVIO_SDA/SCL) を I2C1 スレーブとして動作させ、
`virtIoExp.chip` で指定されたチップのレジスタ動作を模擬する。
ロジックカードの動作中は常に応答する (システムメニュー表示中を含む)。

### MCP23017 の模擬 (`chip` = "mcp23017")

- スレーブアドレスは `virtIoExp.addr` (通常 0x20 = 32)。それ以外のアドレス宛の転送には応答しない (NACK)。
  同一バス上に存在し得る他チップ (ESPboy の MCP4725 など) は模擬しない。
- IOCON.BANK = 0 のレジスタマップ (0x00-0x15) を実装する。レジスタポインタは STOP をまたいで保持し、
  連続アクセスで自動インクリメントする (SEQOP = 0 前提)。
- GPIOA/B の読み出し値のうち、LCIO64-79 にキーが割り当てられたビットにはキーパッド状態を反映する
  (キーマップと負論理指定に従う)。未割り当ての入力ビットは 1 (プルアップ相当) を返す。
- 出力に設定されたピンへの書き込みは OLAT に保持し、読み戻せるようにする。ホストは出力値を使用しない。
- IODIR/GPPU/IPOL 等の設定レジスタは保持・読み戻しのみ行い、入力値の生成には影響させない。
- INTA/INTB 割り込み出力は模擬しない。
- カード起動時 (RESET デアサート時) にレジスタを Power-on 初期値へ戻す。

### PCA9555 の模擬 (`chip` = "pca9555")

- スレーブアドレスは `virtIoExp.addr` (Xiamocon は 0x22 = 34)。それ以外のアドレス宛の転送には応答しない (NACK)。
  同一バス上に存在し得る他チップ (Xiamocon のバッテリー監視 ADC ADC101C027 (0x52) など) は模擬しない。
- コマンドレジスタ 0-7 (Input 0/1、Output 2/3、Polarity Inversion 4/5、Configuration 6/7) を実装する。
  Power-on 初期値は Output = 0xFF、Polarity = 0x00、Configuration = 0xFF (全入力)。
- レジスタポインタは STOP をまたいで保持する。連続アクセス時のオートインクリメントは
  レジスタペア内でのトグルとなる (0↔1、2↔3、4↔5、6↔7。MCP23017 の連番インクリメントとは異なる)。
- Input レジスタの読み出し値は、入力設定ビットはパッドレベル (キー割り当てと負論理指定に従う。
  未割り当てビットは 1 = プルアップ相当)、出力設定ビットは Output レジスタ値とし、
  その全体に Polarity Inversion レジスタによる反転を適用する:
  `Input = ((levels & Config) | (Output & ~Config)) XOR Polarity`。
  **MCP23017 の模擬と異なり、極性反転を入力値の生成に反映する** (将来のカードでの使用を想定)。
- Output レジスタへの書き込みは保持し、読み戻せるようにする。
  機能番号 1 (ディスプレイリセット) が割り当てられた仮想ポート ([03_card_profile.md](03_card_profile.md)) については、
  Configuration で出力に設定されたビットの Output 値が Low の間、LCD をリセット状態として LcdTap へ転送する
  (`inputReset()` 相当)。この転送は段階的対応とし、未対応のホストは当該ポートを無視してよい。
- INT 割り込み出力は模擬しない。
- カード起動時 (RESET デアサート時) にレジスタを Power-on 初期値へ戻す。

## LCD VSYNC 出力

カードプロファイルに機能番号 3 (LCD VSYNC 出力) のポートがある場合、ホストコントローラは
当該 LCIO に PWM で自走パルスを出力する ([03_card_profile.md](03_card_profile.md))。

- 周波数とパルス幅はプロファイルの `vsync` メンバに従う (省略時 60 Hz / 1 ms)。
  パルスは正論理 (非パルス期間 Low、パルス期間 High) とし、ポートのモードに `負論理` が
  指定された場合は反転する。
- 「動作」への遷移では RESET をデアサートする前にパルス出力を開始し、「停止」への遷移では
  RESET をアサートした後に停止する。システムメニュー表示中も出力を続ける。
  「停止」状態では非パルス期間のレベルで駆動する。
- 物理 LCD のリフレッシュとは同期しない (カード上の MCU から同期信号に見えることだけを目的とする)。

## ゲームモード

ホストシェル側のキーパッド入力をロジックカードに送信する。
ロジックカードからの LCD 描画命令は LcdTap (submodule/lcdtap/) で受けてフレームバッファに描画し、ホストシェル側の LCD に表示する。
ホストシェル側 LCD への転送は、フレームバッファの更新された部分のみに対して行う。

ホームボタンが押されたらフレームバッファの表示は中止してシステムメニューを表示する。
システムメニュー表示中もロジックカードは動作を続ける。
もう一度ホームボタンが押されたらシステムメニューを閉じてフレームバッファの表示を再開する。

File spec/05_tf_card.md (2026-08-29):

# TF カード

- ルートディレクトリ
  - `WCB/`: WildCardBoy 用ディレクトリ
    - `Cards/`: ロジックカード毎のディレクトリ
      - `<カードID>/`: 例 `TinyJoypad/`
        - `Apps/`: ロジックカード上の MCU に書き込むバイナリファイルを格納するディレクトリ
          - バイナリファイル...

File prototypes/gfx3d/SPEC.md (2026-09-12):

# 3D レンダリングライブラリのプロトタイプ

## 概要

WildCardBoy のシステムメニューの背景で用いる 3D レンダリングライブラリのプロトタイプ。

- 省メモリ: フレームバッファや Z バッファは持たず、ライン単位でレンダリングする
- 実機ではモデルデータ (頂点配列やテクスチャ) は Flash に配置する想定
- 作業メモリはユーザが与えるアリーナから確保する (ライブラリ内部で malloc しない)
- スキャンライン法によるラスタライズ
- 平行光源、拡散反射、環境光、テクスチャ、環境マッピング対応
- シェーディングはグーローシェーディング (頂点単位でライティングし、スパン内で色を線形補間)
- 名前空間: `shapoco::gfx3d`
- 特定のアーキテクチャに依存しない (ピュア C++)
- 将来的に組み込み向けの汎用的な 3D ライブラリとしてスピンアウトする可能性あり。

## 数学系

`math3d.hpp` にまとめて実装する

### 構造体

- `vec2f`: 2D ベクトル (x, y) を表す構造体
- `vec3f`: 3D ベクトル (x, y, z) を表す構造体
- `colorf`: 色 (r, g, b, a) を表す構造体
- `mat4f`: 4x4 行列を表す構造体

### 関数

各種ベクトル演算、行列演算、変換行列生成関数を提供する。

## データ構造

### 座標系

- OpenGL 互換の右手系座標系

### 頂点 (`Vertex`)

- 位置ベクトル (`vec3f`)
- 法線ベクトル (`vec3f`)
- テクスチャ座標 (`vec2f`, 環境マッピング時は未使用)

### 頂点バッファ (`VertexBuffer`)

- 頂点数 (`uint16_t`)
- 頂点の配列へのポインタ (`const Vertex*`)

### テクスチャ (`Texture`)

- 幅 (`int16_t`、2 の冪)
- 高さ (`int16_t`、2 の冪)
- ピクセルデータ (RGB565) へのポインタ (`const uint16_t*`)

### ブレンドモード (`BlendMode`)

```c++
enum class BlendMode : uint8_t {
    NONE,  // ブレンドなし (上書き)
    ALPHA, // アルファブレンディング
    ADD,   // 加算合成
};
```

`NONE` 以外のマテリアルを持つ三角形は半透明として扱われる
(線分リストで既存スパンを削除せず、リスト順にブレンドされる)。

### マテリアル (`Material`)

- 拡散反射色 (`colorf`)
- 環境反射色 (`colorf`)
- テクスチャへのポインタ (`const Texture*`)
- ブレンドモード (`BlendMode`)
- フラグ (`uint32_t`)
    - テクスチャを有効にするかどうか
    - 環境マッピングを有効にするかどうか (有効時はテクスチャを環境マップとして使用する)
    - 両面描画するかどうか (無効時は反時計回りを表としてバックフェイスカリングを行う)

### プリミティブの種類 (`PrimitiveType`)

- `TRIANGLES`: 3 つの頂点で構成される三角形の集合
- `TRIANGLE_STRIP`: 連続する頂点列で構成される三角形ストリップ
- `TRIANGLE_FAN`: 連続する頂点列で構成される三角形ファン

### プリミティブ (`Primitive`)

- プリミティブの種類 (`PrimitiveType`)
- 頂点バッファへのポインタ (`const VertexBuffer*`)
- 頂点インデックスの数 (`uint16_t`, 面の数はこれから算出)
- 頂点インデックスの配列へのポインタ (`const uint16_t*`)
- マテリアルへのポインタ (`const Material*`)

## API

```c++
namespace shapoco::gfx3d {

// ライブラリを初期化する (w, h: 画面サイズ、arena, arenaSize: 作業メモリ)
void init(int16_t w, int16_t h, void* arena, size_t arenaSize);
void deinit(); // ライブラリを終了する

void beginScene(); // シーンの構築を開始する
void endScene(); // シーンの構築を終了する

void loadIdentity(); // 現在の変換行列を単位行列にリセットする
void translate(const vec3f& v); // 現在の変換行列に平行移動を適用する
void translate(float x, float y, float z); // 同上
void rotate(float angle, const vec3f& axis); // 現在の変換行列に回転を適用する
void rotate(float angle, float x, float y, float z); // 同上
void scale(const vec3f& v); // 現在の変換行列にスケーリングを適用する
void scale(float x, float y, float z); // 同上

void pushState(); // 現在の変換行列とマテリアルをスタックに保存する
void popState(); // スタックから変換行列とマテリアルを復元する

void setMaterial(const Material& mat); // 現在のマテリアルを設定する
void putPrimitive(const Primitive& prim); // プリミティブをシーンに追加する
// 中心とサイズを指定して立方体をシーンに追加する。
// divs は各面の一辺あたりの分割数 (面ごとに divs x divs 個のポリゴンに分割される)。
// 中間点の UV は補間で生成される。
void putCube(const vec3f& center, const vec3f& size, int divs = 1);

void enableParallelLight(const vec3f& dir, const colorf& col); // 平行光源を設定する
void disableParallelLight(); // 平行光源を無効にする

void enableEnvironmentLight(const colorf& col); // 環境光を設定する
void disableEnvironmentLight(); // 環境光を無効にする

void setClearColor(const colorf& col); // 背景色を設定する (スパンで覆われないピクセルはこの色で塗られる)

void setPerspectiveProjection(float fovY, float aspect, float zNear, float zFar); // 透視投影行列を設定する
void setOrthographicProjection(float left, float right, float bottom, float top, float zNear, float zFar); // 正射影行列を設定する

void beginRender(); // レンダリングを開始する
void endRender(); // レンダリングを終了する
void render(int16_t x, int16_t y, int16_t w, int16_t h, uint16_t* dst, uint32_t stride); // 指定された領域をレンダリングする

// 統計 (アリーナの使用量、三角形数と容量、線分プールのピークと容量、あふれで破棄した数)
Stats getStats();

};
```

## シーンの構築

1. `beginScene()` を呼び出す
2. ノードやプリミティブを追加してシーンを構築する
3. `endScene()` を呼び出す

`putPrimitive()` はプリミティブを個々のポリゴンに分解し、頂点単位のライティング (グーローシェーディング) と投影変換までを実施する。
変換結果は内部のトライアングルバッファに保持され、`render()` でラスタライズされる。
`render()` は複数の領域に分けて呼び出される可能性がある。
プリミティブ内で複数のポリゴンが共有する頂点は、小さなダイレクトマップキャッシュで変換を使い回す。

この段階で以下の三角形は破棄される:

- ニア平面 (zNear) をまたぐ、またはニア平面より手前にある三角形
- バックフェイスカリングが有効なマテリアルで、裏を向いている三角形

## メモリ確保

- ライブラリ内部で動的メモリ確保 (malloc/new) は行わず、`init()` でユーザが与えたアリーナからすべての作業メモリ (トライアングルバッファ、線分リスト等) を確保する
- トライアングルバッファがあふれた場合、以降の三角形はそのフレームでは破棄される

## レンダリングパイプライン

### `beginRender()`

トライアングルバッファ内の三角形を遠い順にソートする (三角形本体ではなくインデックス配列を並べ替える)。
不透明な線分同士の前後関係は `render()` での深度比較で解決されるため、
このソートは主に半透明の合成順を決めるためのもの。

### `render()`

呼び出しの先頭で、領域内のラインごとに「そのラインから交差し始める三角形」のリスト (深度順) を作る。
各ラインでは、このリストをアクティブリスト (現在のラインと交差する三角形、深度順) にマージし、
通り過ぎた三角形を外しながら、以下の処理を行う:

1. 線分リストをクリアする
2. アクティブリストの三角形 (遠い順) に対して以下の処理を行う
    1. 当該三角形のライン上の 2 つの交点から線分を求める。線分は「左端ピクセルでの属性値 + 1 ピクセルあたりの増分」
       (深度は float、色とテクスチャ座標は 16 ビット小数の固定小数点) として表す
    2. 線分をリストに追加する。不透明な線分は x 昇順のリストで管理し (互いに重ならない)、半透明な線分は登録順 (遠い順) の別リストで管理する。
       重なりについては、重なり区間の中央で深度 (スクリーン空間で線形な NDC 深度) を比較し、
       奥側が不透明・半透明のどちらであっても、手前が不透明ならば奥側の重なり部分を削除する。
       三角形単位のソート順だけに頼らないため、大きなポリゴンと小さなポリゴンの前後関係も正しく解決される。
       半透明が手前の場合は両方残す
3. 不透明な線分を x 順にラスタライズし、その隙間を背景色で塗る。その後、半透明な線分をリスト順にマテリアルの `BlendMode` に従って合成する

ピクセル単位の処理はすべて整数演算で行う。ブレンドモード x テクスチャ有無 x フラット (3 頂点の色が同一) の組み合わせごとにループを特殊化し、
フラットで不透明・テクスチャなしの線分は単純なフィルになる。テクスチャ座標のラップはビットマスクで行うため、
テクスチャの幅・高さは 2 の冪でなければならない。加算合成の色は頂点単位で不透明度を乗算済みとして扱う。

テクスチャ座標と頂点色 (グーローシェーディング) はアフィン補間とする。
テクスチャの透視歪みが問題になる場合は、コンパイルオプション `GFX3D_PERSPECTIVE_CORRECT_UV=1` で
透視補正 (スクリーン空間で線形な (u/w, v/w, 1/w) を float で補間し、ピクセル単位で除算する) を有効にできる (デフォルト無効)。

### `endRender()`

特にすることはない。

## ライブラリ実装

- `prototypes/gfx3d/lib/include/shapoco/gfx3d/`: ライブラリユーザへ公開するヘッダファイル
- `prototypes/gfx3d/lib/src/`: ライブラリの実装ファイル

ライブラリユーザは `#include "shapoco/gfx3d/gfx3d.hpp"` を使用してライブラリを利用する。

## サンプル実装

ブラウザ上で動作確認するためのサンプルコード。解像度は 480x320 で固定。

- `prototypes/gfx3d/example/common/scene.cpp`: gfx3d ライブラリを使用して適当なシンプルなシーンを構築する (WASM / 実機サンプルで共通)
- `prototypes/gfx3d/example/wasm/cpp/main.cpp`: フレームバッファを確保し、共通シーンを構築してレンダリングする
- `docs/prototypes/gfx3d/index.html`: canvas 上でレンダリング結果を確認するための HTML ファイル
- `prototypes/gfx3d/example/wasm/` の配下に WASM ビルド環境を構築する
    - 必要に応じて JavaScript または TypeScript 用のサブディレクトリを作成する
- マウスまたはキーボードでカメラ操作

## 参考資料

以前別のプロジェクトで作成した 3D ライブラリが以下にあるので参考にしてください。
ただしこちらは Z バッファ法によるラスタライズになっているので注意してください。
https://github.com/shapoco/xiamocon/tree/main/cpp/library

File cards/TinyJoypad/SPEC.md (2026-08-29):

# TinyJoypad カード

TinyJoypad カードは、ATtiny85 を搭載した小型ゲーム機「Tinyjoypad」の CPU 周辺回路を WildCardBoy のロジックカードとして実装したもの。

## カードID

`TinyJoypad`

## カード I/F

|信号名|ATtiny85 割り当て|説明|
|---|---|---|
|LCAUDIO_L|PB4|オーディオ左チャンネル|
|LCAUDIO_R|PB4|オーディオ右チャンネル|
|LCIO2|PB0|SSD1309 制御信号 (SDA)|
|LCIO3|PB2|SSD1309 制御信号 (SCL)|
|LCIO5|抵抗を介して PB5|左キー (open-drain)|
|LCIO6|抵抗を介して PB5|右キー (open-drain)|
|LCIO7|抵抗を介して PB3|上キー (open-drain)|
|LCIO8|抵抗を介して PB3|下キー (open-drain)|
|LCIO9|PB1|Aボタン (open-drain)|
|LCIO13|PB5|RESET (open-drain)|

LCIO2、3、9、13 は ATtiny85 へのプログラムの書き込み時にも使用される。

|信号名|ATtiny85 割り当て|説明|
|---|---|---|
|LCIO2|PB0|MOSI|
|LCIO3|PB2|SCK|
|LCIO9|PB1|MISO|
|LCIO13|PB5|RESET (open-drain)|

方向キーはロジックカード上で次のように配線され、各キーの押下状態は ATtiny85 の ADC で読み取られる (Tinyjoypad の仕様)。

```
                            LC3V3
                              |
                            22kOhm
                              |
LCIO5 (LCKEY_L) --- 88kOhm ---+--- PB5 (ATtiny85)
                              |
LCIO6 (LCKEY_R) --- 33kOhm ---+

                            LC3V3
                              |
                            22kOhm
                              |
LCIO7 (LCKEY_U) --- 33kOhm ---+--- PB3 (ATtiny85)
                              |
LCIO8 (LCKEY_D) --- 88kOhm ---+
```

## EEPROM

[profile.json](profile.json) を参照 (生成済みイメージ: [profile.hex](profile.hex))。

## プログラミング

LCIO2、3、9、13 を使用して ATtiny85 にプログラムを書き込む。
他の LCIO は High-Z でなければならない。

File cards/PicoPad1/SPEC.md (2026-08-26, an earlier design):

# PicoPad1/PicoPad2 カード

PicoPad1/PicoPad2 カードは、Raspberry Pi Pico / Pico 2 を搭載した小型ゲーム機「PicoPad」および「PicoPad2」の CPU 周辺回路を WildCardBoy のロジックカードとして実装したもの。

## カードID

`PicoPad1` または `PicoPad2`

## カード I/F

|信号名|Pico 割り当て|説明|
|---|---|---|
|LCAUDIO_L|GPIO15|オーディオ左チャンネル|
|LCAUDIO_R|GPIO15|オーディオ右チャンネル|
|LCIO0|GPIO20|ST7789 制御信号 (RST)|
|LCIO1|GPIO21|ST7789 制御信号 (CS)|
|LCIO2|GPIO22|ST7789 制御信号 (SCLK)|
|LCIO3|GPIO23|ST7789 制御信号 (MOSI)|
|LCIO4|GPIO24|ST7789 制御信号 (DC)|
|LCIO8|GPIO11|TF カード制御信号 (MOSI)|
|LCIO9|GPIO13|TF カード制御信号 (CS)|
|LCIO10|GPI10|TF カード制御信号 (SCK)|
|LCIO11|GPI12|TF カード制御信号 (MISO)|
|LCIO12|GPIO12|BOOTSEL|
|LCIO13|GPIO13|RESET|
|LCIO32|GPIO3|左ボタン|
|LCIO33|GPIO2|右ボタン|
|LCIO34|GPIO4|上ボタン|
|LCIO35|GPIO5|下ボタン|
|LCIO36|GPIO7|Aボタン|
|LCIO37|GPIO6|Bボタン|
|LCIO38|GPIO9|Xボタン|
|LCIO39|GPIO8|Yボタン|
|LCUSB_DP|USB D+|USB D+|
|LCUSB_DM|USB D-|USB D-|

## EEPROM

T.B.D.

## プログラミング

BOOTSEL と RESET を使って Pico を MSC モードにし、USB 経由で Pico にプログラムを書き込む。
UF2 転送完了後も Pico 側では Flash への書き込みが継続中である可能性に注意すること。

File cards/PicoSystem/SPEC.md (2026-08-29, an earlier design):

# PicoSystem カード

PicoSystem カードは、RP2040 を搭載した Pimoroni の小型ゲーム機「[PicoSystem](https://shop.pimoroni.com/products/picosystem)」の
CPU 周辺回路を WildCardBoy のロジックカードとして実装したもの。
PicoSystem 用のアプリバイナリ (UF2) をそのまま実行することを目標とする。

## カードID

`PicoSystem`

## LCD I/F 方式: デシリアライザによる 8bit パラレル化

PicoSystem のファームウェアは画面転送時に SPI クロックを最大約 62.5 MHz
(システムクロック 250 MHz へのオーバークロック時) で駆動する。
ホストシェルの SPI 直接キャプチャでは 312 MHz 化しても化けが解消しなかったため
(サンプリングマージン不足)、カード上にデシリアライザを搭載して 8bit パラレルに変換し、
WildCardBus の 8bit パラレル LCD 固定割り当てで接続する
(LcdTap-Pico2 Universal の PicoSystem 対応と同一構成。
[lcdtap issue 0001](../../submodule/lcdtap/issues/0001_spi_input_change_to_parallel.md) /
[0003](../../submodule/lcdtap/issues/0003_shift_register_change_to_hc595.md))。

```
RP2040 GPIO6 (SCLK) ──┬─→ 74HC595 SRCLK
                      └─→ 74HC4040 CP
RP2040 GPIO7 (MOSI) ────→ 74HC595 SER
RP2040 GPIO5 (CS)   ──┬─→ 74HC4040 CLR (active-high)
                      └─→ LCIO1 (LCLCD_CS)
74HC4040 Q3 (SCLK/8) ──→ 74AHC1G04 ──→ BCLK ──┬─→ LCIO2 (LCLCD_WR)
                                              └─→ 74HC595 RCLK
74HC595 Q1-Q8 (D0-D7) ─────────────────────────→ LCIO3-10 (LCLCD_D0-7)
RP2040 GPIO9 (DC) ─────────────────────────────→ LCIO11 (LCLCD_DC)
RP2040 GPIO4 (LCD_RST) ────────────────────────→ LCIO0 (LCLCD_RST)
```

CS=High の間はカウンタがクリアされ BCLK が出ないため、ホスト側は BCLK の
立ち上がり毎に D0-7 と DC をサンプリングするだけでよい (ピクセルレートは最大 7.8125 MHz)。

## カード I/F

|信号名|接続|説明|
|---|---|---|
|LCAUDIO_L|GPIO11|オーディオ (ローパスフィルタ + カップリングコンデンサ経由)|
|LCAUDIO_R|GPIO11|同上|
|LCIO0|GPIO4|LCLCD_RST|
|LCIO1|GPIO5|LCLCD_CS|
|LCIO2|74AHC1G04 出力|LCLCD_WR (BCLK = SCLK/8)|
|LCIO3-10|74HC595 Q1-Q8|LCLCD_D0-7|
|LCIO11|GPIO9|LCLCD_DC|
|LCIO12|QSPI_SS|BOOTSEL (open-drain、負論理)|
|LCIO13|RUN|RESET (open-drain、負論理)|
|LCIO32-39|GPIO16-23|ボタン (カード上の PCA9555 経由。後述)|
|LCUSB_DP|USB D+|UF2 書き込み用|
|LCUSB_DM|USB D-|UF2 書き込み用|

## LCD VSYNC (T.B.D.)

PicoSystem のファームウェアは ST7789 の TE 信号 (GPIO8) の立ち上がりエッジをポーリングして
フレーム同期を行う。8bit パラレル構成では LCIO0-11 が LCD I/F で占有され、ホストシェルの
VSYNC 出力 (機能番号 3) に割り当てられる空き LCIO が無いため、**現状はカード上に小型 MCU を
追加して GPIO8 へ自走パルス (60 Hz 程度) を生成する想定 (詳細 T.B.D.)**。
カードプロファイルでは VSYNC 出力ポートおよび `vsync` メンバを使用しない。

## ボタン

キーパッド I/F は I2C (カード上の PCA9555、devaddr=0x20、LCAUX 経由)。ボタンはアクティブ Low。

**注意: PicoSystem SDK の `init_inputs()` はピン番号をマスクとして OR するバグがあり、
ボタン用 GPIO16-23 の内部プルアップは実際には有効化されない** (実機 PicoSystem は基板上の
外付けプルアップで動作している)。RP2040 のパッドはリセット既定でプルダウンのため、
オープンドレイン駆動ではボタンが全押し状態に見える。
そのため PCA9555 は **プッシュプル出力 + 負論理 (m=34)** とし、非押下時に High を能動的に駆動する。

|PCA9555ポート|RP2040 割り当て|ボタン|
|---|---|---|
|P0_0|GPIO22|左|
|P0_1|GPIO21|右|
|P0_2|GPIO23|上|
|P0_3|GPIO20|下|
|P0_4|GPIO18|A|
|P0_5|GPIO19|B|
|P0_6|GPIO17|X|
|P0_7|GPIO16|Y|

## 不使用ピン

|ピン|処置|
|---|---|
|GPIO2|未接続 (公式 SDK では CHARGE_LED として出力 Low 固定)|
|GPIO12|未接続 (バックライト PWM)|
|GPIO13-15|未接続 (RGB LED)|
|GPIO24|カード上でプルアップ (充電ステータス。非充電相当に固定)|
|GPIO26|カード上の分圧抵抗で満充電相当の電圧を入力 (バッテリーレベル ADC。
分圧比は PicoSystem 実機の回路に合わせて調整する)|

## カード上の部品

|箇所|部品/値|備考|
|---|---|---|
|シフトレジスタ|74HC595|シリアル→パラレル変換|
|分周カウンタ|74HC4040|SCLK/8 生成。CLR ← CS|
|インバータ|74AHC1G04|BCLK 生成 (74HC4040 Q3 の反転)|
|RUN プルアップ|10kΩ||
|QSPI_SS プルアップ|10kΩ|ブートストラップ (BOOTSEL)|
|GPIO24 プルアップ|10kΩ|充電ステータス非アサート固定|
|GPIO26 分圧|適宜|バッテリーレベル入力|
|VSYNC 生成|小型 MCU (T.B.D.)|GPIO8 へ自走パルス|

## MCU について

本カードの MCU が初期ロットの RP2040 (B0、ROM v1) の場合、PicoSystem 公式ビルド
(`PICO_RP2040_B0_SUPPORTED=0`) は double 演算関数の欠落により起動直後に
panic("missing double function") で停止する。アプリは `PICO_BOARD=pico` または
`PICO_RP2040_B0_SUPPORTED=1` でビルドしたものを使用すること。

## EEPROM

[profile.json](profile.json) を参照 (生成済みイメージ: [profile.hex](profile.hex))。

## プログラミング

BOOTSEL と RESET を使って RP2040 を MSC モードにし、USB 経由で UF2 を書き込む
([spec/04_host_controller.md](../../spec/04_host_controller.md))。
UF2 転送完了後も RP2040 側では Flash への書き込みが継続中である可能性に注意すること。

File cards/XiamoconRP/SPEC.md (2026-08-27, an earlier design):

# Xiamocon RP2350 カード

Xiamocon RP2350 カードは、RP2350 を搭載した小型ゲーム機「[Xiamocon](https://github.com/shapoco/xiamocon)」(RP2350 版) の
CPU 周辺回路を WildCardBoy のロジックカードとして実装したもの。
Xiamocon 用のアプリバイナリ (UF2) をそのまま実行することを目標とする。
ESP32-S3 版の Xiamocon は対象外。

## カードID

`XiamoconRP`

## 電源

RP2350 とその周辺回路は LC3V3 で動作する (カード上のレギュレータは不要)。

## カード I/F

RP2350 (+ QSPI Flash) と WildCardBus の接続:

|信号名|RP2350 割り当て|説明|
|---|---|---|
|LCAUDIO_L|GPIO1|サウンド出力 (RC フィルタ + カップリングコンデンサ経由)|
|LCAUDIO_R|GPIO1|同上|
|LCIO0|未接続|LCLCD_RST は使用しない (ディスプレイリセットは仮想 I/O エキスパンダの PORTA-5。後述)|
|LCIO1|GPIO5|LCLCD_CS|
|LCIO2|GPIO2|LCLCD_SCK (TF と共有バス。後述)|
|LCIO3|GPIO3|LCLCD_MOSI (TF と共有バス。後述)|
|LCIO4|GPIO28|LCLCD_DC|
|LCIO6|GPIO6|LCVIO_SDA|
|LCIO7|GPIO7|LCVIO_SCL|
|LCIO8|GPIO3|LCTF_MOSI|
|LCIO9|GPIO0|LCTF_CS|
|LCIO10|GPIO2|LCTF_SCK|
|LCIO11|GPIO4|LCTF_MISO|
|LCIO12|QSPI_SS|BOOTSEL (open-drain、負論理)|
|LCIO13|RUN|RESET (open-drain、負論理)|
|LCUSB_DP|USB D+|UF2 書き込み用|
|LCUSB_DM|USB D-|UF2 書き込み用|

### LCD / TF の共有バス

Xiamocon は LCD と TF カードが SPI バス (SCK = GPIO2、MOSI = GPIO3) を共有し、CS でスレーブを選択する。
カード上で GPIO2 は LCIO2 (LCLCD_SCK) と LCIO10 (LCTF_SCK) の両方へ、
GPIO3 は LCIO3 (LCLCD_MOSI) と LCIO8 (LCTF_MOSI) の両方へ分岐して接続する。
TF カードへのアクセス中も LCIO2/3 がトグルするが、ホスト側の SPI キャプチャは LCLCD_CS でゲートされるため問題ない
(実機の共有バスと同じトポロジ)。

### 不使用ピン

|ピン|処置|
|---|---|
|GPIO26|未接続 (Xiamocon 実機では拡張ポート用)|
|GPIO27|電源ボタン (ハイアクティブ)。使用しないためカード上でプルダウン|

## カード上の抵抗

|箇所|値|備考|
|---|---|---|
|LCVIO_SDA/SCL プルアップ|4.7kΩ x2|I2C バス ([spec/02_wildcardbus.md](../../spec/02_wildcardbus.md))|
|RUN プルアップ|10kΩ||
|QSPI_SS プルアップ|10kΩ|ブートストラップ (BOOTSEL)|
|GPIO27 プルダウン|10kΩ|電源ボタン非アサート固定|

## 仮想 I/O エキスパンダ

Xiamocon は PCA9555 (devaddr=0x22) をボタン入力・ディスプレイリセット・オーディオミュートなどに使用する。
カードには実チップを搭載せず、ホストコントローラが模擬する ([spec/04_host_controller.md](../../spec/04_host_controller.md))。

|PCA9555ポート|LCIO|割り当て|
|---|---|---|
|PORTA-0..3|(未使用)|拡張ポート用 (ユーザ定義)|
|PORTA-4|(未使用)|ペリフェラルイネーブル (アプリが出力設定する。ホストは使用しない)|
|PORTA-5|LCIO69|ディスプレイリセット (LCLCD_RST 相当として扱う。ホスト側は段階的対応)|
|PORTA-6|(未使用)|オーディオミュート (今回は不使用。将来的にホストシェル側にミュート制御機能を設ける可能性あり)|
|PORTA-7|LCIO71|ファンクションスイッチ (ホストシェル側の L/R バンパー両方を割り当て)|
|PORTB-0|LCIO72|A ボタン (ホストシェル側は B ボタン)|
|PORTB-1|LCIO73|B ボタン (ホストシェル側は A ボタン)|
|PORTB-2|LCIO74|Y ボタン (ホストシェル側は X ボタン)|
|PORTB-3|LCIO75|X ボタン (ホストシェル側は Y ボタン)|
|PORTB-4|LCIO76|上キー|
|PORTB-5|LCIO77|下キー|
|PORTB-6|LCIO78|左キー|
|PORTB-7|LCIO79|右キー|

すべてローアクティブ。

Xiamocon 実機で同一バス上にあるバッテリー監視 ADC (ADC101C027、devaddr=0x52) は搭載も模擬もしない
(probe が NACK になったときにファームウェアがハングする場合は Xiamocon 側を修正する)。

## EEPROM

[profile.json](profile.json) を参照 (生成済みイメージ: [profile.hex](profile.hex))。

## プログラミング

BOOTSEL と RESET を使って RP2350 を MSC モードにし、USB 経由で UF2 を書き込む
([spec/04_host_controller.md](../../spec/04_host_controller.md))。
UF2 転送完了後も RP2350 側では Flash への書き込みが継続中である可能性に注意すること。

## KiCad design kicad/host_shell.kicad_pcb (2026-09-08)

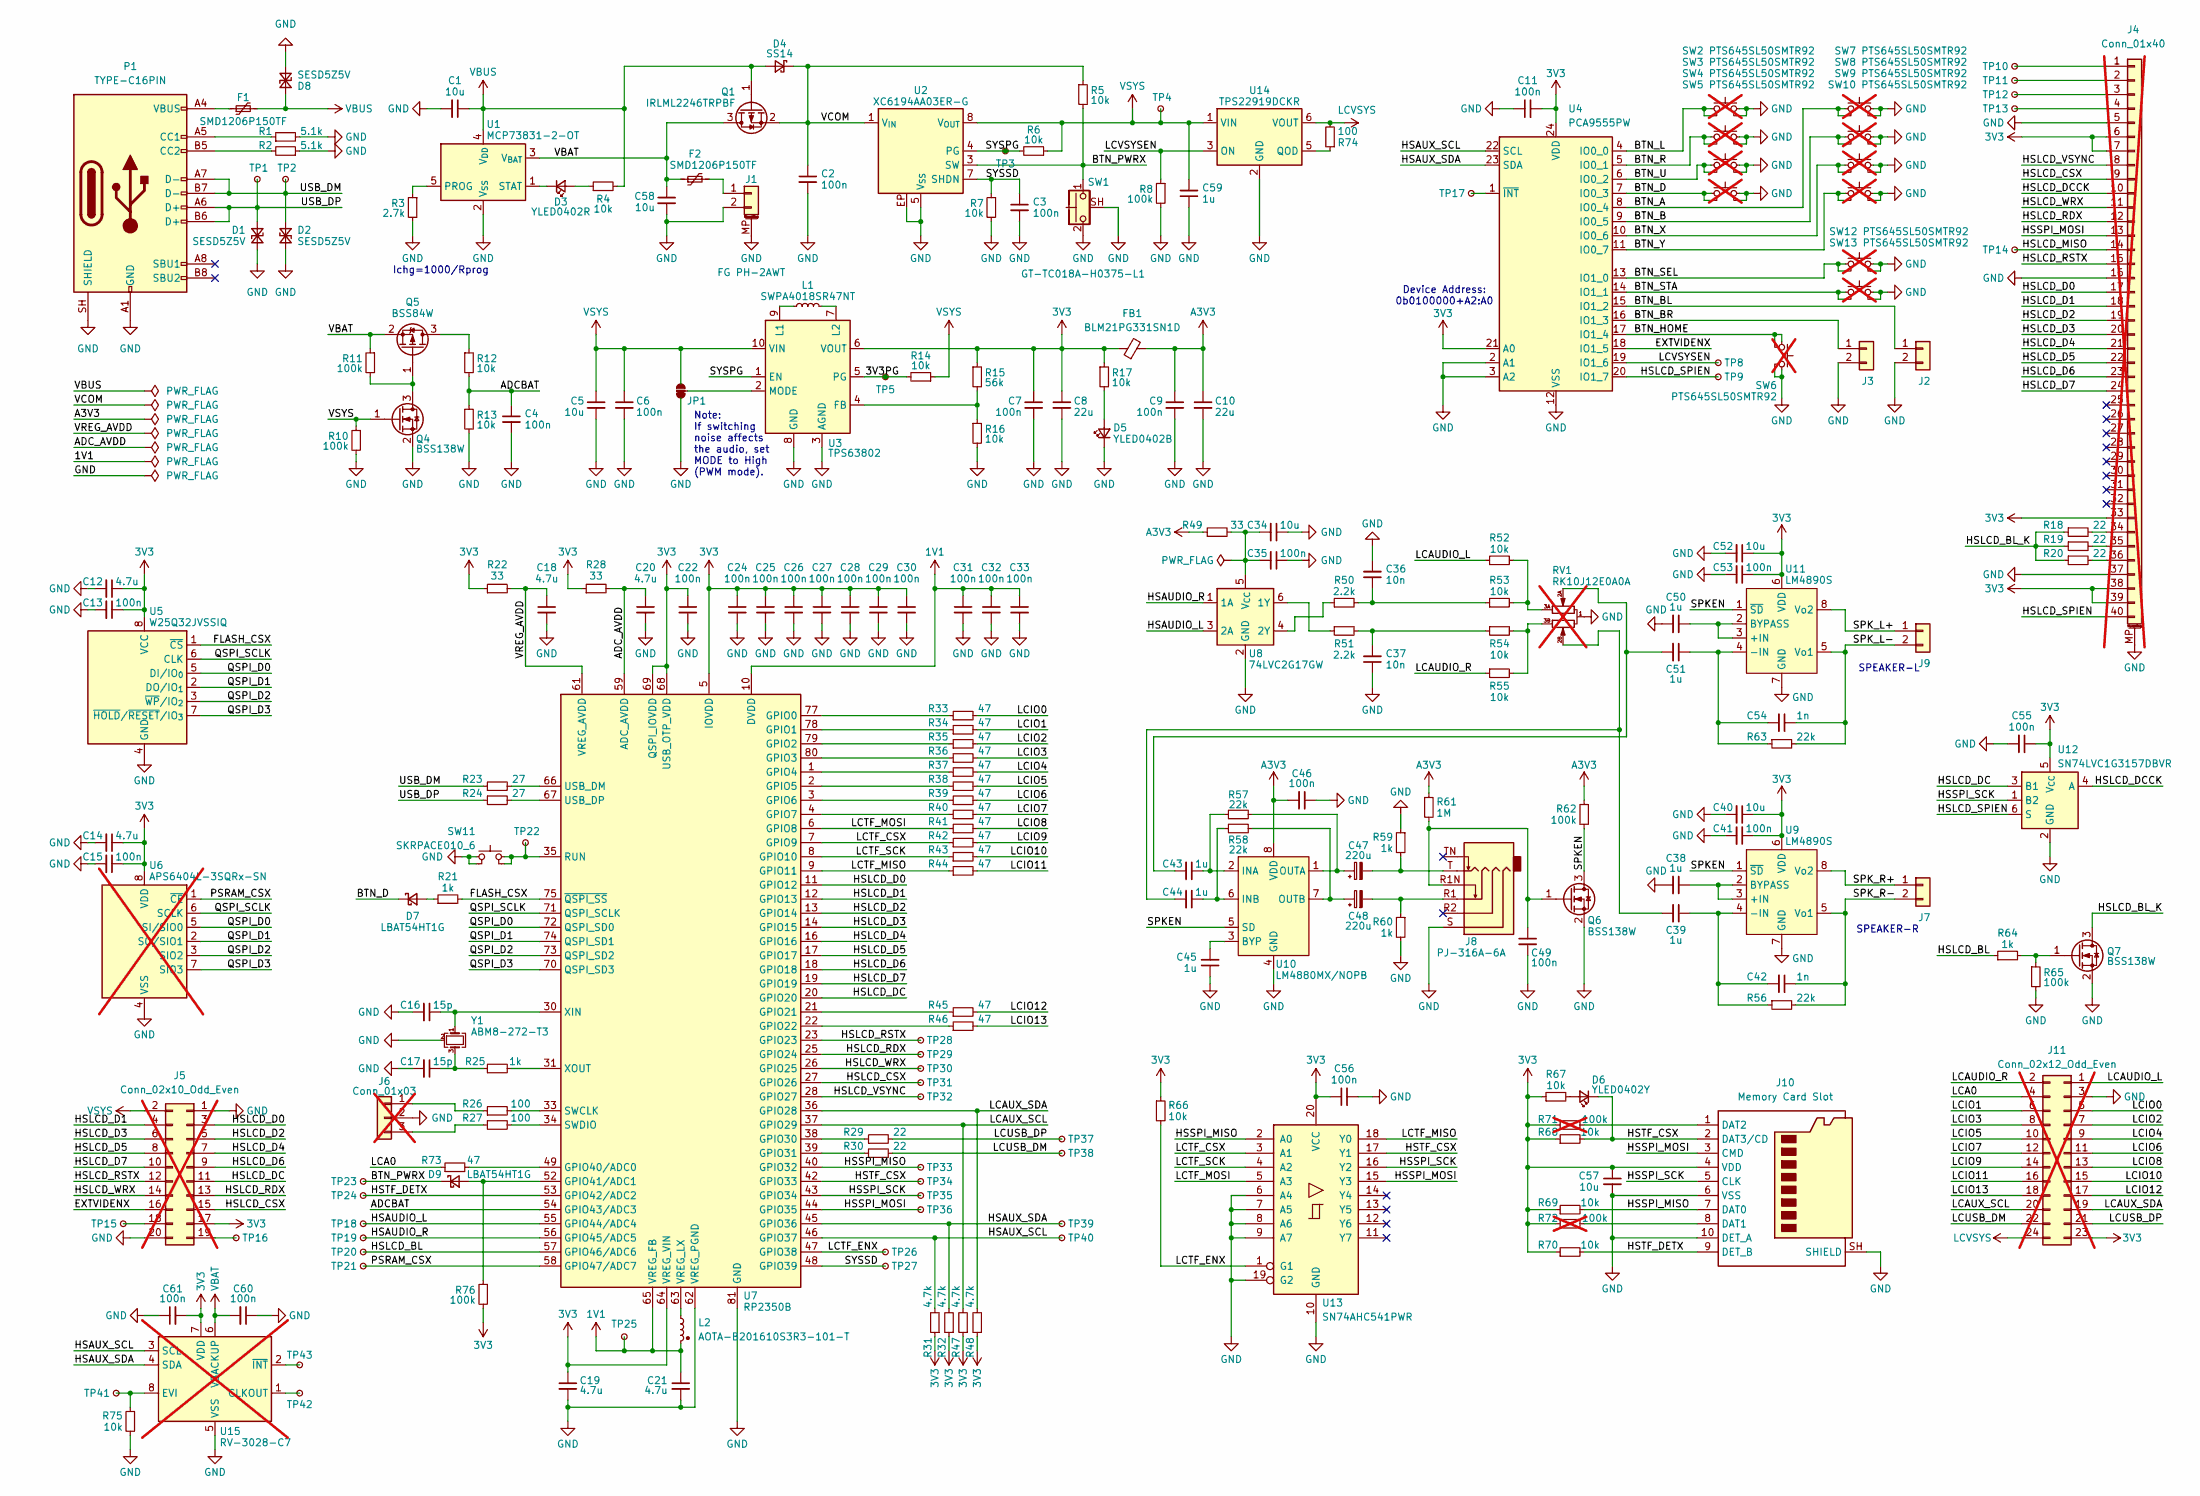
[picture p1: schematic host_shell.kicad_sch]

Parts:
C1, C5, C34, C40, C52, C57, C58: 10u; C_0603_1608Metric; LCSC C1691
C2, C3, C4, C6, C7, C9, C11, C13, C15, C22, C24, C25, C26, C27, C28, C29, C30, C31, C32, C33, C35, C41, C46, C49, C53, C55, C56, C60, C61: 100n; C_0402_1005Metric; LCSC C1525
C8, C10: 22u; C_0603_1608Metric; LCSC C59461
C12, C14, C18, C19, C20, C21: 4.7u; C_0603_1608Metric; LCSC C19666
C16, C17: 15p; C_0402_1005Metric; LCSC C1548
C36, C37: 10n; C_0402_1005Metric; LCSC C15195
C38, C39, C43, C44, C45, C50, C51, C59: 1u; C_0402_1005Metric; LCSC C52923
C42, C54: 1n; C_0402_1005Metric; LCSC C1523
C47, C48: 220u; CP_Elec_6.3x5.4; LCSC C3345
D1, D2, D8: SESD5Z5V; D_SOD-523; LCSC C19631222
D3: YLED0402R; LED_0402_1005Metric_Pad0.77x0.64mm_HandSolder; LCSC C21260817
D4: SS14; D_SMA; LCSC C2480
D5: YLED0402B; LED_0402_1005Metric_Pad0.77x0.64mm_HandSolder; LCSC C30584803
D6: YLED0402Y; LED_0402_1005Metric_Pad0.77x0.64mm_HandSolder; LCSC C20608782
D7, D9: LBAT54HT1G; D_SOD-323; LCSC C12744
F1, F2: SMD1206P150TF; Fuse_1206_3216Metric; LCSC C20802
FB1: BLM21PG331SN1D; L_0805_2012Metric; LCSC C74764
J1: FG PH-2AWT; JST_PH_S2B-PH-SM4-TB_1x02-1MP_P2.00mm_Horizontal; LCSC C2763693
J2, J3: Conn_01x02; SolderWirePad_1x02_SMD_2.5x1.5mm
J4: Conn_01x40; FFC_Conn_40P_Top_Hand; not fitted
J5: Conn_02x10_Odd_Even; PinSocket_2x10_P2.54mm_Horizontal; not fitted
J6: Conn_01x03; PinHeader_1x03_P2.54mm_Vertical; not fitted
J7, J9: Conn_01x02; SolderWirePad_2x01_SMD_2.5x1.5mm
J8: PJ-316A-6A; Jack_3.5mm_PJ-316A-6A_Horizontal; LCSC C128987
J10: Memory Card Slot; microSD_HC_Hirose_DM3AT-SF-PEJM5; LCSC C114218
J11: Conn_02x12_Odd_Even; PinSocket_2x12_P2.54mm_Horizontal; not fitted
JP1: SolderJumper_3_Bridged12; SolderJumper-3_P1.3mm_Bridged12_RoundedPad1.0x1.5mm
L1: SWPA4018SR47NT; L_Sunlord_SWPA4018S; LCSC C527613
L2: AOTA-B201610S3R3-101-T; LCSC C42411119
P1: TYPE-C16PIN; USB_C_Receptacle_HCTL_HC-TYPE-C-16P-01A; LCSC C393939
Q1: IRLML2246TRPBF; SOT-23; LCSC C127272
Q4, Q6, Q7: BSS138W; SOT-323_SC-70; LCSC C504052
Q5: BSS84W; SOT-323_SC-70; LCSC C919394
R1, R2: 5.1k; R_0402_1005Metric; LCSC C25905
R3: 2.7k; R_0402_1005Metric; LCSC C25885
R4, R5, R6, R7, R12, R13, R14, R16, R17, R52, R53, R54, R55, R66, R67, R68, R69, R70, R75: 10k; R_0402_1005Metric; LCSC C25744
R8, R10, R11, R62, R65, R76: 100k; R_0402_1005Metric; LCSC C25741
R15: 56k; R_0402_1005Metric; LCSC C25567
R18, R19, R20, R29, R30: 22; R_0402_1005Metric; LCSC C25092
R21, R25, R59, R60, R64: 1k; R_0402_1005Metric; LCSC C11702
R22, R28, R49: 33; R_0402_1005Metric; LCSC C25105
R23, R24: 27; R_0402_1005Metric; LCSC C25100
R26, R27, R74: 100; R_0402_1005Metric; LCSC C25076
R31, R32, R47, R48: 4.7k; R_0402_1005Metric; LCSC C25900
R33, R34, R35, R36, R37, R38, R39, R40, R41, R42, R43, R44, R45, R46, R73: 47; R_0402_1005Metric; LCSC C25118
R50, R51: 2.2k; R_0402_1005Metric; LCSC C25879
R56, R57, R58, R63: 22k; R_0402_1005Metric; LCSC C25768
R61: 1M; R_0402_1005Metric; LCSC C26083
R71, R72: 100k; R_0402_1005Metric; LCSC C25741; not fitted
RV1: RK10J12E0A0A; RK10J1xE; LCSC C351176; not fitted
SW1: GT-TC018A-H0375-L1; LCSC C963235
SW2, SW3, SW4, SW5, SW6, SW7, SW8, SW9, SW10, SW12, SW13: PTS645SL50SMTR92; SW_SPST_PTS645Sx43SMTR92; not fitted
SW11: SKRPACE010_6; SW_Push_1P1T_NO_Vertical_Wuerth_434133025816; LCSC C139797
TP1, TP2, TP3, TP4, TP5, TP8, TP9, TP10, TP11, TP12, TP13, TP14, TP15, TP16, TP17, TP18, TP19, TP20, TP21, TP22, TP23, TP24, TP25, TP26, TP27, TP28, TP29, TP30, TP31, TP32, TP33, TP34, TP35, TP36, TP37, TP38, TP39, TP40, TP41, TP42, TP43: TestPoint_Small; TestPoint_Pad_D1.0mm
U1: MCP73831-2-OT; SOT-23-5; LCSC C14879
U2: XC6194AA03ER-G; USP-8B06; LCSC C18221112
U3: TPS63802; LCSC C2845237
U4: PCA9555PW; TSSOP-24_4.4x7.8mm_P0.65mm; LCSC C128392
U5: W25Q32JVSSIQ; SOIC-8_5.3x5.3mm_P1.27mm; LCSC C179173
U6: APS6404L-3SQRx-SN; SOP-8_3.76x4.96mm_P1.27mm; not fitted
U7: RP2350B; QFN-80-1EP_10x10mm_P0.4mm_EP3.4x3.4mm; LCSC C42415655
U8: 74LVC2G17GW; SOT-363_SC-70-6; LCSC C19829576
U9, U11: LM4890S; MSOP-8_3x3mm_P0.65mm; LCSC C329452
U10: LM4880MX/NOPB; SOIC-8_3.9x4.9mm_P1.27mm; LCSC C2872533
U12: SN74LVC1G3157DBVR; SOT-23-6; LCSC C10426
U13: SN74AHC541PWR; TSSOP-20_4.4x6.5mm_P0.65mm; LCSC C406865
U14: TPS22919DCKR; SOT-363_SC-70-6; LCSC C2149796
U15: RV-3028-C7; MicroCrystal_C7_SON-8_1.5x3.2mm_P0.9mm; LCSC C3304278; not fitted
Y1: ABM8-272-T3; Crystal_SMD_3225-4Pin_3.2x2.5mm; LCSC C20625731

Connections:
1V1: C21.1, C31.1, C32.1, C33.1, L2.1, TP25.1 (1_1), U7.10 (DVDD), U7.32 (DVDD), U7.51 (DVDD), U7.65 (VREG_FB)
3V3: C7.1, C8.1, C11.2, C12.1, C13.1, C14.1, C15.1, C19.1, C22.1, C24.1, C25.1, C26.1, C27.1, C28.1, C29.1, C30.1, C40.1, C41.1, C52.1, C53.1, C55.1, C56.1, C57.1, C61.2, FB1.1, J4.6, J4.7, J4.33, J4.38, J4.39, J5.17, J10.4 (VDD), J11.23, R15.1, R17.1, R22.1, R28.1, R31.1, R32.1, R47.1, R48.1, R66.1, R67.1, R68.1, R69.1, R70.1, R71.1, R72.1, R76.2, U3.6 (VOUT), U4.21 (A0), U4.24 (VDD), U5.8 (VCC), U6.8 (VDD), U7.5 (IOVDD), U7.15 (IOVDD), U7.24 (IOVDD), U7.29 (IOVDD), U7.41 (IOVDD), U7.50 (IOVDD), U7.60 (IOVDD), U7.64 (VREG_VIN), U7.68 (USB_OTP_VDD), U7.69 (QSPI_IOVDD), U7.76 (IOVDD), U9.6 (VDD), U11.6 (VDD), U12.5 (V_{CC}), U13.20 (VCC), U15.7 (VDD)
/3V3PG: R14.2, TP5.1 (1_1), U3.5 (PG)
/ADCBAT: C4.1, R12.2, R13.1, U7.54 (GPIO43/ADC3)
/ADC_AVDD: C20.1, R28.2, U7.59 (ADC_AVDD)
/BTN_A: SW7.1, U4.8 (IO0_4)
/BTN_B: SW8.1, U4.9 (IO0_5)
/BTN_BL: J2.1, U4.15 (IO1_2)
/BTN_BR: J3.1, U4.16 (IO1_3)
/BTN_D: D7.1 (K), SW5.1, U4.7 (IO0_3)
/BTN_HOME: SW6.1, U4.17 (IO1_4)
/BTN_L: SW2.1, U4.4 (IO0_0)
/BTN_PWRX: D9.1 (K), R5.2, SW1.1, TP23.1 (1_1), U2.3 (SW)
/BTN_R: SW3.1, U4.5 (IO0_1)
/BTN_SEL: SW12.1, U4.13 (IO1_0)
/BTN_STA: SW13.1, U4.14 (IO1_1)
/BTN_U: SW4.1, U4.6 (IO0_2)
/BTN_X: SW9.1, U4.10 (IO0_6)
/BTN_Y: SW10.1, U4.11 (IO0_7)
/EXTVIDENX: J5.16, U4.18 (IO1_5)
/FLASH_CSX: R21.2, U5.1 (~CS), U7.75 (~QSPI_SS)
/HSAUDIO_L: TP18.1 (1_1), U7.55 (GPIO44/ADC4), U8.3 (2A)
/HSAUDIO_R: TP19.1 (1_1), U7.56 (GPIO45/ADC5), U8.1 (1A)
/HSAUX_SCL: R31.2, TP40.1 (1_1), U4.22 (SCL), U7.46 (GPIO37), U15.3 (SCL)
/HSAUX_SDA: R32.2, TP39.1 (1_1), U4.23 (SDA), U7.45 (GPIO36), U15.4 (SDA)
/HSLCD_BL: R64.1, TP20.1 (1_1), U7.57 (GPIO46/ADC6)
/HSLCD_BL_K: Q7.3 (D), R18.1, R19.1, R20.1
/HSLCD_CSX: J4.9, J5.15, TP31.1 (1_1), U7.27 (GPIO26)
/HSLCD_D0: J4.17, J5.3, U7.11 (GPIO12)
/HSLCD_D1: J4.18, J5.4, U7.12 (GPIO13)
/HSLCD_D2: J4.19, J5.5, U7.13 (GPIO14)
/HSLCD_D3: J4.20, J5.6, U7.14 (GPIO15)
/HSLCD_D4: J4.21, J5.7, U7.16 (GPIO16)
/HSLCD_D5: J4.22, J5.8, U7.17 (GPIO17)
/HSLCD_D6: J4.23, J5.9, U7.18 (GPIO18)
/HSLCD_D7: J4.24, J5.10, U7.19 (GPIO19)
/HSLCD_DC: J5.11, U7.20 (GPIO20), U12.3 (B1)
/HSLCD_DCCK: J4.10, U12.4 (A)
/HSLCD_MISO: J4.14, TP14.1 (1_1)
/HSLCD_RDX: J4.12, J5.13, TP29.1 (1_1), U7.25 (GPIO24)
/HSLCD_RSTX: J4.15, J5.12, TP28.1 (1_1), U7.23 (GPIO23)
/HSLCD_SPIEN: J4.40, TP9.1 (1_1), U4.20 (IO1_7), U12.6 (S)
/HSLCD_VSYNC: J4.8, TP32.1 (1_1), U7.28 (GPIO27)
/HSLCD_WRX: J4.11, J5.14, TP30.1 (1_1), U7.26 (GPIO25)
/HSSPI_MISO: J10.7 (DAT0), R69.2, TP33.1 (1_1), U7.40 (GPIO32), U13.2 (A0)
/HSSPI_MOSI: J4.13, J10.3 (CMD), TP36.1 (1_1), U7.44 (GPIO35), U13.15 (Y3)
/HSSPI_SCK: J10.5 (CLK), TP35.1 (1_1), U7.43 (GPIO34), U12.1 (B2), U13.16 (Y2)
/HSTF_CSX: D6.1 (K), J10.2 (DAT3/CD), R68.2, TP34.1 (1_1), U7.42 (GPIO33), U13.17 (Y1)
/HSTF_DETX: J10.9 (DET_B), R70.2, TP24.1 (1_1), U7.53 (GPIO42/ADC2)
/LCA0: J11.4, R73.1
/LCAUDIO_L: J11.1, R52.1
/LCAUDIO_R: J11.2, R55.1
/LCAUX_SCL: J11.20, R47.2, U7.37 (GPIO29)
/LCAUX_SDA: J11.19, R48.2, U7.36 (GPIO28)
/LCIO0: J11.5, R33.2
/LCIO1: J11.6, R34.2
/LCIO2: J11.7, R35.2
/LCIO3: J11.8, R36.2
/LCIO4: J11.9, R37.2
/LCIO5: J11.10, R38.2
/LCIO6: J11.11, R39.2
/LCIO7: J11.12, R40.2
/LCIO8: J11.13, R41.2
/LCIO9: J11.14, R42.2
/LCIO10: J11.15, R43.2
/LCIO11: J11.16, R44.2
/LCIO12: J11.17, R45.2
/LCIO13: J11.18, R46.2
/LCTF_CSX: R42.1, U7.7 (GPIO9), U13.3 (A1)
/LCTF_ENX: R66.2, TP26.1 (1_1), U7.47 (GPIO38), U13.1 (G1)
/LCTF_MISO: R44.1, U7.9 (GPIO11), U13.18 (Y0)
/LCTF_MOSI: R41.1, U7.6 (GPIO8), U13.5 (A3)
/LCTF_SCK: R43.1, U7.8 (GPIO10), U13.4 (A2)
/LCUSB_DM: J11.22, R30.2, TP38.1 (1_1)
/LCUSB_DP: J11.21, R29.2, TP37.1 (1_1)
/LCVSYSEN: R8.1, TP8.1 (1_1), U4.19 (IO1_6), U14.3 (ON)
/PSRAM_CSX: TP21.1 (1_1), U6.1 (~CE), U7.58 (GPIO47/ADC7)
/QSPI_D0: U5.5 (DI/IO_{0}), U6.5 (SI/SIO0), U7.72 (QSPI_SD0)
/QSPI_D1: U5.2 (DO/IO_{1}), U6.2 (SO/SIO1), U7.74 (QSPI_SD1)
/QSPI_D2: U5.3 (~WP/IO_{2}), U6.3 (SIO2), U7.73 (QSPI_SD2)
/QSPI_D3: U5.7 (~HOLD/~RESET/IO_{3}), U6.7 (SIO3), U7.70 (QSPI_SD3)
/QSPI_SCLK: U5.6 (CLK), U6.6 (SCLK), U7.71 (QSPI_SCLK)
/SPKEN: Q6.3 (D), R62.2, U9.1 (~SD), U10.5 (SD), U11.1 (~SD)
/SPK_L+: J9.1, U11.8 (Vo2)
/SPK_L-: C54.1, J9.2, R63.2, U11.5 (Vo1)
/SPK_R+: J7.1, U9.8 (Vo2)
/SPK_R-: C42.1, J7.2, R56.2, U9.5 (Vo1)
/SYSPG: R6.2, TP3.1 (1_1), U2.4 (PG), U3.1 (EN)
/SYSSD: C3.1, R7.1, TP27.1 (1_1), U2.7 (SHDN), U7.48 (GPIO39)
/USB_DM: D2.1 (A1), P1.A7 (D-), P1.B7 (D-), R23.1, TP2.1 (1_1)
/USB_DP: D1.1 (A1), P1.A6 (D+), P1.B6 (D+), R24.1, TP1.1 (1_1)
/VCOM: C2.1, D4.1 (K), Q1.2 (S), R5.1, U2.1 (V_{IN})
/VREG_AVDD: C18.1, R22.2, U7.61 (VREG_AVDD)
A3V3: C9.1, C10.1, C46.2, FB1.2, R49.1, R61.1, R62.1, U10.8 (VDD)
GND: C1.2, C2.2, C3.2, C4.2, C5.2, C6.2, C7.2, C8.2, C9.2, C10.2, C11.1, C12.2, C13.2, C14.2, C15.2, C16.2, C17.2, C18.2, C19.2, C20.2, C21.2, C22.2, C24.2, C25.2, C26.2, C27.2, C28.2, C29.2, C30.2, C31.2, C32.2, C33.2, C34.1, C35.1, C36.2, C37.1, C38.2, C40.2, C41.2, C45.1, C46.1, C49.2, C50.2, C52.2, C53.2, C55.2, C56.2, C57.2, C58.2, C59.1, C60.1, C61.1, D1.2 (A2), D2.2 (A2), D5.1 (K), D8.2 (A2), J1.2, J1.MP (MountPin), J2.2, J3.2, J4.5, J4.16, J4.37, J4.MP (MountPin), J5.1, J5.20, J6.2, J8.S, J10.6 (VSS), J10.10 (DET_A), J10.SH (SHIELD), J11.3, JP1.1 (A), P1.A1 (GND), P1.A12 (GND), P1.B1 (GND), P1.B12 (GND), P1.SH (SHIELD), Q4.2 (S), Q6.2 (S), Q7.2 (S), R1.2, R2.1, R3.2, R7.2, R8.2, R10.2, R13.2, R16.2, R59.1, R60.2, R65.2, R75.2, RV1.1, SW1.2, SW1.SH (B), SW2.2, SW3.2, SW4.2, SW5.2, SW6.2, SW7.2, SW8.2, SW9.2, SW10.2, SW11.1, SW12.2, SW13.2, U1.2 (V_{SS}), U2.5 (V_{SS}), U2.EP, U3.3 (AGND), U3.8 (GND), U4.2 (A1), U4.3 (A2), U4.12 (VSS), U5.4 (GND), U6.4 (VSS), U7.62 (VREG_PGND), U7.81 (GND), U8.2 (GND), U9.7 (GND), U10.4 (GND), U11.7 (GND), U12.2 (GND), U13.6 (A4), U13.7 (A5), U13.8 (A6), U13.9 (A7), U13.10 (GND), U13.19 (G2), U14.2 (GND), U15.5 (VSS), Y1.2 (G), Y1.4 (G)
LCVSYS: J11.24, R74.2, U14.6 (VOUT)
unnamed: C17.1, R25.1, Y1.3
unnamed: C36.1, R50.2, R53.1
unnamed: C37.2, R51.2, R54.1
unnamed: C39.2, C44.2, RV1.2B
unnamed: C43.2, C51.2, RV1.2A
unnamed: C47.2, J8.T, R59.2
unnamed: C48.2, J8.R1, R60.1
unnamed: D3.2 (A), R4.1
unnamed: D3.1 (K), U1.1 (STAT)
unnamed: D5.2 (A), R17.2
unnamed: D6.2 (A), R67.2
unnamed: D7.2 (A), R21.1
unnamed: D9.2 (A), R76.1, U7.52 (GPIO41/ADC1)
unnamed: F1.1, P1.A4 (VBUS), P1.A9 (VBUS), P1.B4 (VBUS), P1.B9 (VBUS)
unnamed: F2.2, J1.1
unnamed: J4.1, TP10.1 (1_1)
unnamed: J4.2, TP11.1 (1_1)
unnamed: J4.3, TP12.1 (1_1)
unnamed: J4.4, TP13.1 (1_1)
unnamed: J4.34, R18.2
unnamed: J4.35, R19.2
unnamed: J4.36, R20.2
unnamed: J5.18, TP15.1 (1_1)
unnamed: J5.19, TP16.1 (1_1)
unnamed: J6.1, R26.1
unnamed: J6.3, R27.1
unnamed: J10.8 (DAT1), R72.2
unnamed: J10.1 (DAT2), R71.2
unnamed: JP1.2 (C), U3.2 (MODE)
unnamed: P1.A5 (CC1), R1.1
unnamed: P1.B5 (CC2), R2.2
unnamed: Q4.3 (D), Q5.1 (G), R11.2
unnamed: Q5.3 (D), R12.1
unnamed: C49.1, J8.R1N, Q6.1 (G), R61.2
unnamed: Q7.1 (G), R64.2, R65.1
unnamed: R52.2, R53.2, RV1.3A
unnamed: R54.2, R55.2, RV1.3B
unnamed: R3.1, U1.5 (PROG)
unnamed: R15.2, R16.1, U3.4 (FB)
unnamed: L1.2, U3.9 (L1)
unnamed: L1.1, U3.7 (L2)
unnamed: TP17.1 (1_1), U4.1 (~INT)
unnamed: R33.1, U7.77 (GPIO0)
unnamed: R34.1, U7.78 (GPIO1)
unnamed: R35.1, U7.79 (GPIO2)
unnamed: R36.1, U7.80 (GPIO3)
unnamed: R37.1, U7.1 (GPIO4)
unnamed: R38.1, U7.2 (GPIO5)
unnamed: R39.1, U7.3 (GPIO6)
unnamed: R40.1, U7.4 (GPIO7)
unnamed: R45.1, U7.21 (GPIO21)
unnamed: R46.1, U7.22 (GPIO22)
unnamed: R29.1, U7.38 (GPIO30)
unnamed: R30.1, U7.39 (GPIO31)
unnamed: R73.2, U7.49 (GPIO40/ADC0)
unnamed: SW11.2, TP22.1 (1_1), U7.35 (RUN)
unnamed: R26.2, U7.33 (SWCLK)
unnamed: R27.2, U7.34 (SWDIO)
unnamed: R23.2, U7.66 (USB_DM)
unnamed: R24.2, U7.67 (USB_DP)
unnamed: L2.2, U7.63 (VREG_LX)
unnamed: C16.1, U7.30 (XIN), Y1.1
unnamed: R25.2, U7.31 (XOUT)
unnamed: R51.1, U8.6 (1Y)
unnamed: R50.1, U8.4 (2Y)
unnamed: C34.2, C35.2, R49.2, U8.5 (V_{CC})
unnamed: C38.1, U9.2 (BYPASS), U9.3 (+IN)
unnamed: C39.1, C42.2, R56.1, U9.4 (-IN)
unnamed: C45.2, U10.3 (BYP)
unnamed: C43.1, R57.1, U10.2 (INA)
unnamed: C44.1, R58.1, U10.6 (INB)
unnamed: C47.1, R57.2, U10.1 (OUTA)
unnamed: C48.1, R58.2, U10.7 (OUTB)
unnamed: C50.1, U11.2 (BYPASS), U11.3 (+IN)
unnamed: C51.1, C54.2, R63.1, U11.4 (-IN)
unnamed: R74.1, U14.5 (QOD)
unnamed: TP42.1 (1_1), U15.1 (CLKOUT)
unnamed: R75.1, TP41.1 (1_1), U15.8 (EVI)
unnamed: TP43.1 (1_1), U15.2 (~INT)
VBAT: C58.1, C60.2, F2.1, Q1.3 (D), Q5.2 (S), R11.1, U1.3 (V_{BAT}), U15.6 (VBACKUP)
VBUS: C1.1, D4.2 (A), D8.1 (A1), F1.2, Q1.1 (G), R4.2, U1.4 (V_{DD})
VSYS: C5.1, C6.1, C59.2, J5.2, JP1.3 (B), Q4.1 (G), R6.1, R10.1, R14.1, TP4.1 (1_1), U2.8 (V_{OUT}), U3.10 (VIN), U14.1 (VIN)

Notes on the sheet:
SPEAKER-L
Note: If switching noise affects the audio, set MODE to High (PWM mode).
Ichg=1000/Rprog
Device Address: 0b0100000+A2:A0
SPEAKER-R

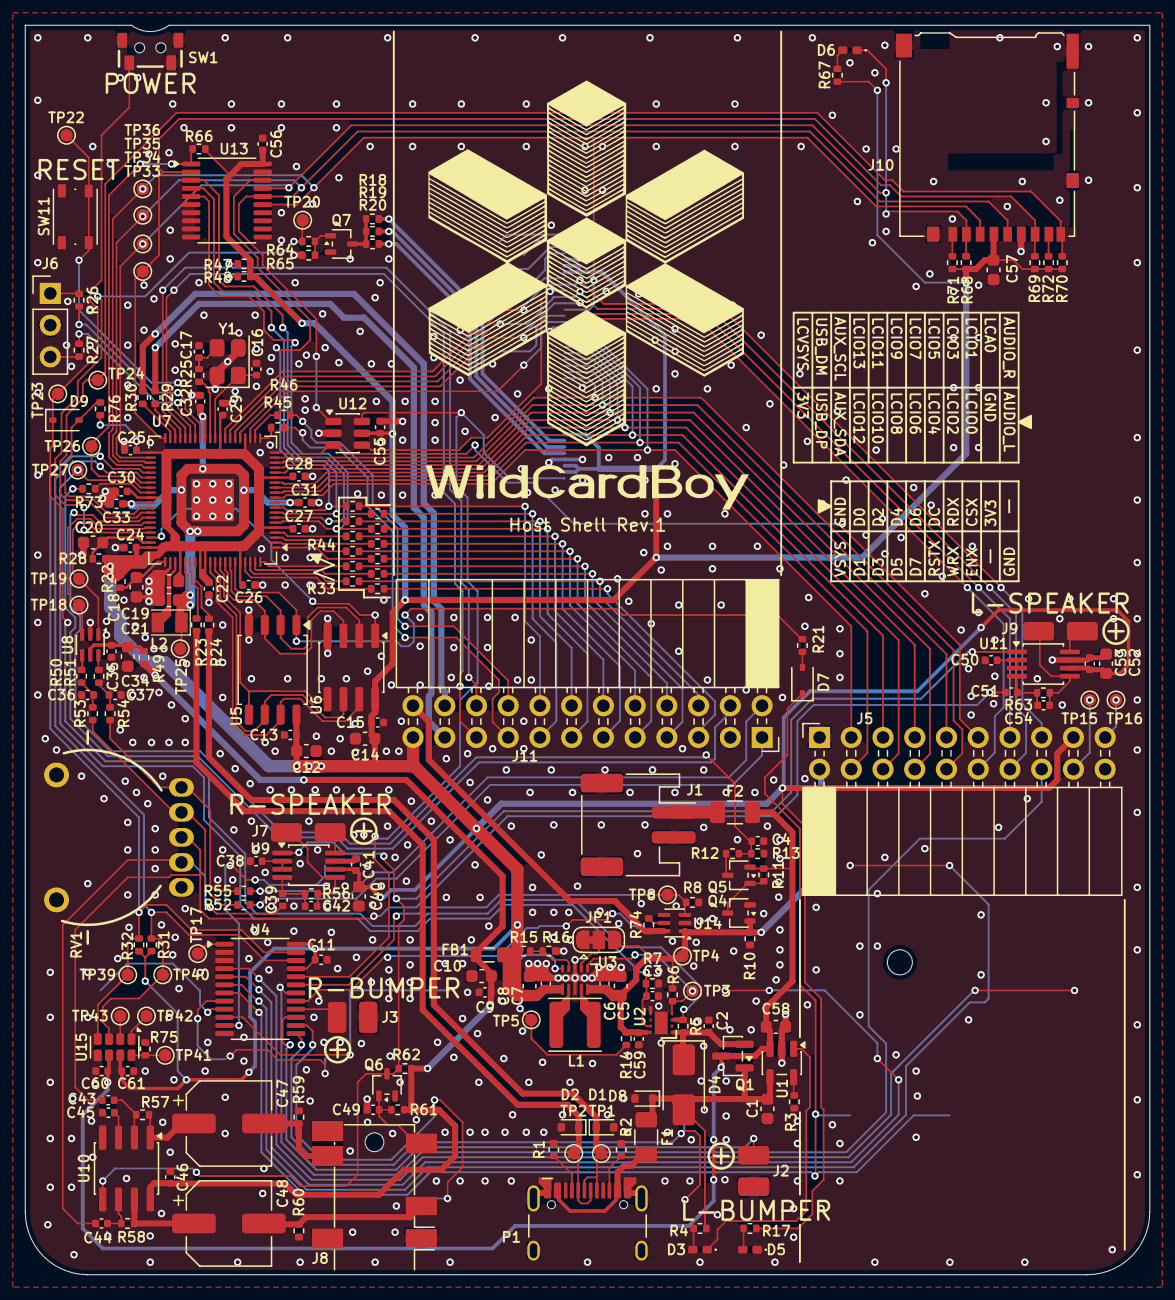
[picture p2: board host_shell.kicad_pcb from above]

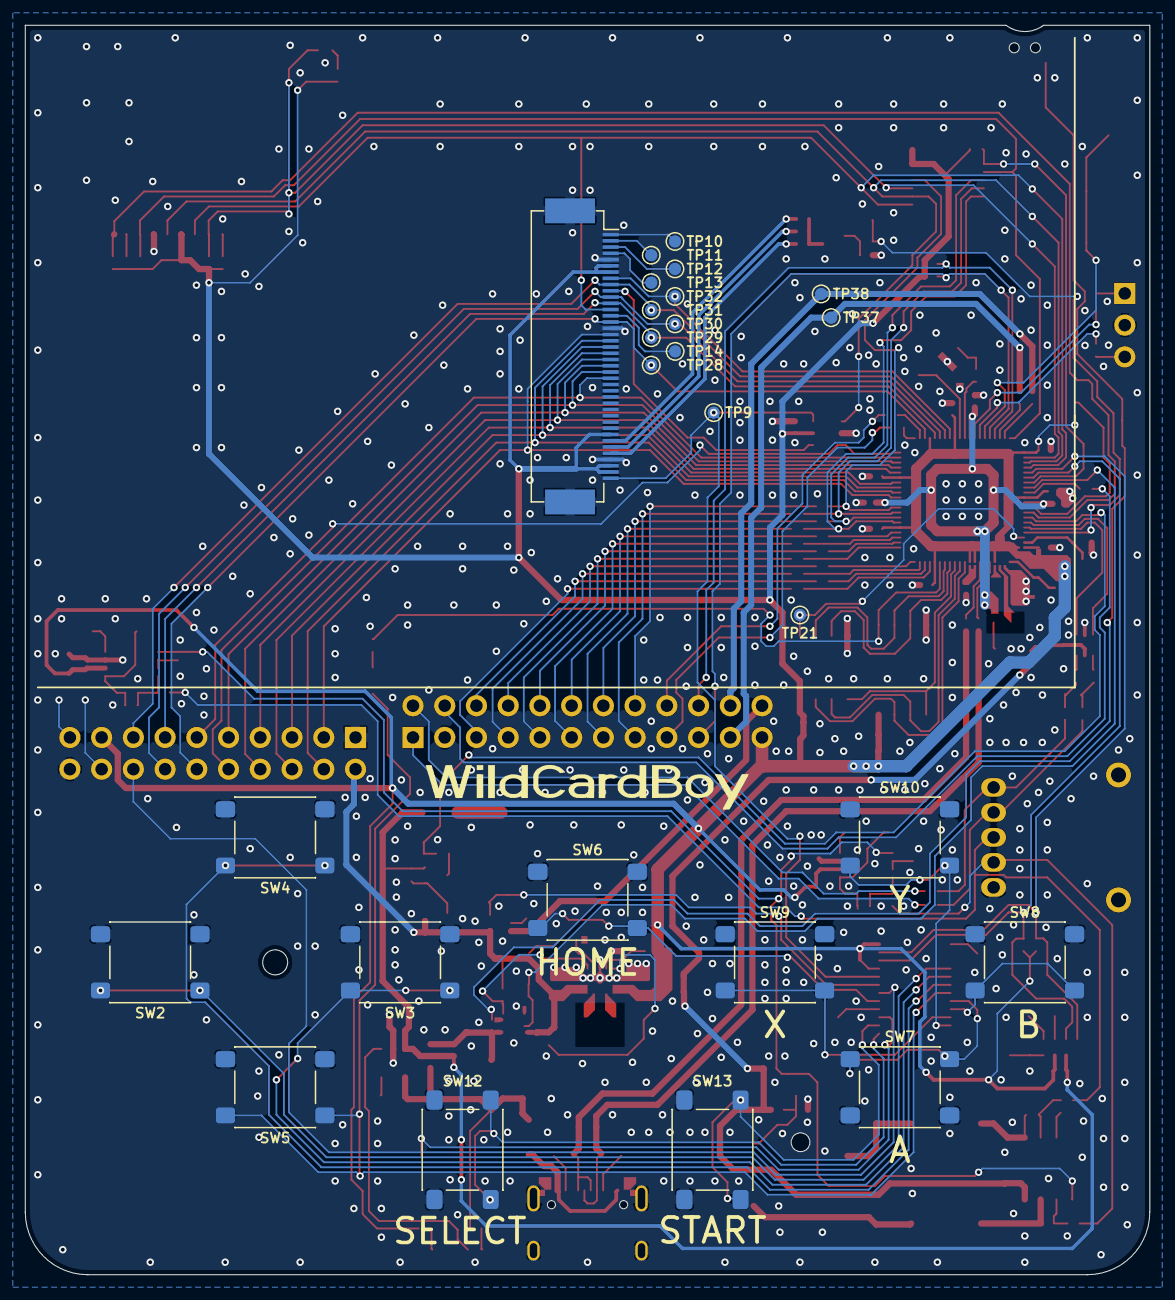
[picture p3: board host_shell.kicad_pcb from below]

Board: 2 copper layers, 90.0 x 100.0 mm, 238 parts (26 on the bottom side), 178 nets.

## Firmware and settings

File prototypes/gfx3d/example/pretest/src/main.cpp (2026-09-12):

// gfx3d prototype performance check on the pretest host shell (prototype
// board). Renders the same scene as the WASM example (example/common/
// scene.cpp) on the host LCD, with the camera driven by the host keypad.
//
//   Rendering: gfx3d renders one band (BAND_H lines) at a time into one of
//              two band buffers; the band is byte-swapped and DMA'd to the
//              LCD while the next band is rendered into the other buffer.
//   Timing   : per-stage averages are printed over USB CDC once a second
//              and shown in the top-left corner of the screen.
//
// Board support (pin map, 312 MHz clock, keypad PCA9555 on HAUX, LCD PIO
// program) comes unmodified from ../../../../pretest. The logic card
// interface is not used.

#include <cmath>
#include <cstdio>

#include "hardware/clocks.h"
#include "pico/stdlib.h"

#include "shapoco/gfx3d/gfx3d.hpp"

#include "aux_i2c.hpp"
#include "board_pins.hpp"
#include "lcd_ili9488.hpp"
#include "overlay.hpp"
#include "scene.hpp"
#include "sys_clock.hpp"

using namespace wcb;
namespace g3 = shapoco::gfx3d;
namespace scene = gfx3d_example;

//-----------------------------------------------------------------------------
// Tunables
//-----------------------------------------------------------------------------
static constexpr int SCREEN_W = LCD_WIDTH;
static constexpr int SCREEN_H = LCD_HEIGHT;
static constexpr int BAND_H = 32;
static constexpr int NUM_BANDS = SCREEN_H / BAND_H;
static_assert(SCREEN_H % BAND_H == 0, "BAND_H must divide the screen height");
static constexpr int OVERLAY_LINES = 3;  // top-left stats text (may straddle bands)

static constexpr size_t ARENA_SIZE = 128 * 1024;  // same as the WASM example
static constexpr float LCD_PIO_BASE_HZ = 150e6f;  // 40 ns/byte at clkdiv 1.0
static constexpr uint64_t STATS_INTERVAL_US = 1000000;

// Camera speeds while a key is held.
static constexpr float CAM_ROT_SPEED = 1.5f;   // rad/s
static constexpr float CAM_ZOOM_SPEED = 1.0f;  // dist *= exp(+-speed * dt)
static constexpr float CAM_DT_MAX = 0.1f;      // clamp for slow frames

#if defined(GFX3D_PERSPECTIVE_CORRECT_UV) && GFX3D_PERSPECTIVE_CORRECT_UV
static constexpr int PERSPECTIVE_UV = 1;
#else
static constexpr int PERSPECTIVE_UV = 0;
#endif

//-----------------------------------------------------------------------------
// Globals
//-----------------------------------------------------------------------------
static Ili9488 gLcd;
alignas(4) static uint16_t gBand[2][SCREEN_W * BAND_H];
alignas(8) static uint8_t gArena[ARENA_SIZE];

struct Camera {
  float yaw, pitch, dist;
};

static void cameraReset(Camera& c) {
  c.yaw = scene::CAM_YAW_INIT;
  c.pitch = scene::CAM_PITCH_INIT;
  c.dist = scene::CAM_DIST_INIT;
}

// Same directions as the arrow / zoom keys of docs/prototypes/gfx3d/main.js.
static void cameraUpdate(Camera& c, uint16_t keys, float dt) {
  if (dt > CAM_DT_MAX) dt = CAM_DT_MAX;
  const float rot = CAM_ROT_SPEED * dt;
  if (keys & HKEY_L) c.yaw -= rot;
  if (keys & HKEY_R) c.yaw += rot;
  if (keys & HKEY_U) c.pitch += rot;
  if (keys & HKEY_D) c.pitch -= rot;
  if (keys & HKEY_A) c.dist *= std::exp(-CAM_ZOOM_SPEED * dt);
  if (keys & HKEY_B) c.dist *= std::exp(CAM_ZOOM_SPEED * dt);
  if (c.pitch < scene::CAM_PITCH_MIN) c.pitch = scene::CAM_PITCH_MIN;
  if (c.pitch > scene::CAM_PITCH_MAX) c.pitch = scene::CAM_PITCH_MAX;
  if (c.dist < scene::CAM_DIST_MIN) c.dist = scene::CAM_DIST_MIN;
  if (c.dist > scene::CAM_DIST_MAX) c.dist = scene::CAM_DIST_MAX;
}

// Per-stage time accumulators (us), reset every STATS_INTERVAL_US.
struct Stats {
  uint32_t frames;
  uint64_t keyUs;     // keypad read (I2C)
  uint64_t sceneUs;   // sceneBuild(): transform + lighting + projection
  uint64_t sortUs;    // beginRender(): depth sort
  uint64_t renderUs;  // render() over all bands
  uint64_t swapUs;    // overlay + byte swap
  uint64_t waitUs;    // waiting for the previous band's DMA + setWindow
  uint32_t frameMaxUs;
  uint32_t renderBandMaxUs;
};

static inline float avgMs(uint64_t us, uint32_t frames) {
  return frames ? static_cast<float>(us) / frames / 1000.0f : 0.0f;
}

//-----------------------------------------------------------------------------
// main
//-----------------------------------------------------------------------------
int main() {
  sysClockInit312();
  stdio_init_all();
  printf("\n=== gfx3d pretest ===\n");
  printf("clk_sys %lu Hz, %dx%d, band %d lines, arena %u B, perspective UV %d\n",
         static_cast<unsigned long>(clock_get_hz(clk_sys)), SCREEN_W, SCREEN_H, BAND_H,
         static_cast<unsigned>(ARENA_SIZE), PERSPECTIVE_UV);

  Ili9488::Pins lcdPins = {PIN_LCD_D0, PIN_LCD_DC, PIN_LCD_WR,
                           PIN_LCD_RD, PIN_LCD_CS, PIN_LCD_RST};
  const float lcdClkDiv = static_cast<float>(clock_get_hz(clk_sys)) / LCD_PIO_BASE_HZ;
  if (!gLcd.init(pio0, 0, lcdPins, lcdClkDiv)) panic("LCD PIO init failed");
  gLcd.clear(0x0000);

  auxI2cInit();

  scene::sceneInit();
  g3::init(SCREEN_W, SCREEN_H, gArena, sizeof(gArena));

  Camera cam;
  cameraReset(cam);
  bool paused = false;
  bool overlay = true;
  float animT = 0.0f;
  uint16_t prevKeys = 0;

  Stats st = {};
  char ovLine[OVERLAY_LINES][SCREEN_W / OVERLAY_GLYPH_W + 1] = {"measuring...", "", ""};

  uint64_t prevFrameUs = time_us_64();
  uint64_t lastStatsUs = prevFrameUs;

  while (true) {
    const uint64_t frameStart = time_us_64();
    const float dt = static_cast<float>(frameStart - prevFrameUs) * 1e-6f;
    const uint32_t frameUs = static_cast<uint32_t>(frameStart - prevFrameUs);
    prevFrameUs = frameStart;
    if (frameUs > st.frameMaxUs) st.frameMaxUs = frameUs;

    //--- keypad / camera ---------------------------------------------------
    uint16_t keys = 0;
    hostKeysRead(&keys);  // keys = 0 on error
    const uint16_t edge = keys & ~prevKeys;
    prevKeys = keys;
    if (edge & HKEY_STA) paused = !paused;
    if (edge & HKEY_SEL) overlay = !overlay;
    if (edge & HKEY_X) cameraReset(cam);
    cameraUpdate(cam, keys, dt);
    if (!paused) animT += dt;
    const uint64_t t0 = time_us_64();

    //--- scene -------------------------------------------------------------
    scene::sceneBuild(animT, cam.yaw, cam.pitch, cam.dist,
                      static_cast<float>(SCREEN_W) / SCREEN_H);
    const uint64_t t1 = time_us_64();
    g3::beginRender();
    const uint64_t t2 = time_us_64();

    //--- bands -------------------------------------------------------------
    // Band i goes to gBand[i & 1]. While band i renders, band i-1 (the other
    // buffer) is on the DMA; band i-2 used this buffer and was waited for
    // before band i-1 started.
    for (int i = 0; i < NUM_BANDS; ++i) {
      uint16_t* buf = gBand[i & 1];
      const int y = i * BAND_H;

      const uint64_t b0 = time_us_64();
      g3::render(0, static_cast<int16_t>(y), SCREEN_W, BAND_H, buf, SCREEN_W);
      const uint64_t b1 = time_us_64();

      if (overlay && y < OVERLAY_LINES * OVERLAY_GLYPH_H) {
        // Rows outside this band are clipped by overlayDrawText().
        for (int l = 0; l < OVERLAY_LINES; ++l) {
          overlayDrawText(buf, SCREEN_W, SCREEN_W, BAND_H, 0, l * OVERLAY_GLYPH_H - y, ovLine[l],
                          0xFFFF, 0x0000);
        }
      }
      Ili9488::swapBytes(buf, SCREEN_W * BAND_H);
      const uint64_t b2 = time_us_64();

      if (i == 0) {
        gLcd.setWindow(0, 0, SCREEN_W - 1, SCREEN_H - 1);  // waits for the last DMA
      } else {
        gLcd.waitDma();
      }
      const uint64_t b3 = time_us_64();
      gLcd.writeBytesAsync(buf, SCREEN_W * BAND_H * 2);

      const uint32_t bandUs = static_cast<uint32_t>(b1 - b0);
      st.renderUs += bandUs;
      if (bandUs > st.renderBandMaxUs) st.renderBandMaxUs = bandUs;
      st.swapUs += b2 - b1;
      st.waitUs += b3 - b2;
    }
    g3::endRender();
    const g3::Stats gs = g3::getStats();

    st.keyUs += t0 - frameStart;
    st.sceneUs += t1 - t0;
    st.sortUs += t2 - t1;
    st.frames++;

    //--- statistics ----------------------------------------------------------
    const uint64_t now = time_us_64();
    if (now - lastStatsUs >= STATS_INTERVAL_US) {
      const float fps = st.frames * 1e6f / static_cast<float>(now - lastStatsUs);
      const float frameMs = st.frames ? static_cast<float>(now - lastStatsUs) / st.frames / 1000.0f : 0.0f;
      printf("[gfx3d] fps=%.2f frame=%.2fms (max %.2f) key=%.2f scene=%.2f sort=%.2f"
             " render=%.2f (band max %.2f) swap=%.2f lcdwait=%.2f"
             " | tri=%d/%d(drop %d) span=%d/%d(drop %d) arena=%u/%u"
             " | cam yaw=%.2f pitch=%.2f dist=%.2f%s\n",
             fps, frameMs, st.frameMaxUs / 1000.0f, avgMs(st.keyUs, st.frames),
             avgMs(st.sceneUs, st.frames), avgMs(st.sortUs, st.frames),
             avgMs(st.renderUs, st.frames), st.renderBandMaxUs / 1000.0f,
             avgMs(st.swapUs, st.frames), avgMs(st.waitUs, st.frames), gs.triCount,
             gs.triCapacity, gs.triDropped, gs.spanPeak, gs.spanCapacity, gs.spanDropped,
             static_cast<unsigned>(gs.arenaUsed), static_cast<unsigned>(gs.arenaSize), cam.yaw,
             cam.pitch, cam.dist, paused ? " (paused)" : "");
      snprintf(ovLine[0], sizeof(ovLine[0]), "%5.1f fps  %6.2f ms/frame%s", fps, frameMs,
               paused ? "  PAUSED" : "");
      snprintf(ovLine[1], sizeof(ovLine[1]), "scene %.2f  sort %.2f  render %.2f  lcd %.2f",
               avgMs(st.sceneUs, st.frames), avgMs(st.sortUs, st.frames),
               avgMs(st.renderUs, st.frames), avgMs(st.waitUs, st.frames));
      // Triangle / span pool usage (last frame) and the arena bytes they occupy.
      snprintf(ovLine[2], sizeof(ovLine[2]), "tri %d/%d%s  span %d/%d%s  arena %.1f/%.0fKB %d%%",
               gs.triCount, gs.triCapacity, gs.triDropped ? "!" : "", gs.spanPeak,
               gs.spanCapacity, gs.spanDropped ? "!" : "", gs.arenaUsed / 1024.0f,
               gs.arenaSize / 1024.0f,
               static_cast<int>(gs.arenaUsed * 100 / (gs.arenaSize ? gs.arenaSize : 1)));
      st = {};
      lastStatsUs = now;
    }
  }
  return 0;
}

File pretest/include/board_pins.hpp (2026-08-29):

#pragma once

// WildCardBoy host controller pin map (see spec/01_host_interfaces.md, spec/02_wildcardbus.md) and constants shared by
// the pretest firmware.

#include <cstdint>

namespace wcb {

//-----------------------------------------------------------------------------
// Host LCD (ILI9488, 8080 8-bit parallel)
//-----------------------------------------------------------------------------
static constexpr uint PIN_LCD_RST = 15;
static constexpr uint PIN_LCD_D0 = 16;  // D0..D7 = GPIO16..23 (contiguous)
static constexpr uint PIN_LCD_DC = 24;
static constexpr uint PIN_LCD_WR = 25;  // NOTE: also PICO_DEFAULT_LED_PIN
static constexpr uint PIN_LCD_RD = 26;
static constexpr uint PIN_LCD_CS = 27;

// Logical (landscape) size. The panel is 320x480 portrait, rotated via MADCTL.
static constexpr uint16_t LCD_WIDTH = 480;
static constexpr uint16_t LCD_HEIGHT = 320;

//-----------------------------------------------------------------------------
// TF card (SPI0 pin group) and the TF card mux
//-----------------------------------------------------------------------------
static constexpr uint PIN_HTF_MISO = 32;  // SPI0 RX
static constexpr uint PIN_HTF_CS = 33;    // GPIO-controlled
static constexpr uint PIN_HTF_SCK = 34;   // SPI0 SCK
static constexpr uint PIN_HTF_MOSI = 35;  // SPI0 TX
// Low = TF card wired to the logic card, High = to the host controller.
// Pulled up on the board. While Low the HTF_* pins must be Hi-Z.
static constexpr uint PIN_LCTF_ENAX = 38;

//-----------------------------------------------------------------------------
// AUX I2C buses. Both pin pairs map to the I2C0 controller (GPIO % 4 == 0/1),
// so exactly one pair is switched to the I2C function at a time; the idle
// pair sits Hi-Z. This keeps card hot-plug glitches on LCAUX away from the
// host bus (HAUX).
//-----------------------------------------------------------------------------
// HAUX: host-side devices (keypad PCA9555).
static constexpr uint PIN_HAUX_SDA = 36;
static constexpr uint PIN_HAUX_SCL = 37;
// LCAUX: logic-card-side devices (ID EEPROM, card PCA9555 on other cards).
static constexpr uint PIN_LCAUX_SDA = 28;
static constexpr uint PIN_LCAUX_SCL = 29;
static constexpr uint32_t AUX_I2C_BAUD = 400 * 1000;

static constexpr uint8_t ADDR_HOST_KEYPAD = 0x21;  // PCA9555 (host, HAUX)
static constexpr uint8_t ADDR_CARD_KEYPAD = 0x20;  // PCA9555 (card, LCAUX) = LCIO32-47
static constexpr uint8_t ADDR_CARD_EEPROM = 0x50;  // 24LC256 (card, LCAUX)

// Host keypad bits as returned by PCA9555 (P0 = bits 0..7, P1 = bits 8..15).
// Inputs are active-low on the wire; hostKeysRead() returns them already
// inverted (1 = pressed).
static constexpr uint16_t HKEY_L = 1u << 0;
static constexpr uint16_t HKEY_R = 1u << 1;
static constexpr uint16_t HKEY_U = 1u << 2;
static constexpr uint16_t HKEY_D = 1u << 3;
static constexpr uint16_t HKEY_A = 1u << 4;
static constexpr uint16_t HKEY_B = 1u << 5;
static constexpr uint16_t HKEY_X = 1u << 6;
static constexpr uint16_t HKEY_Y = 1u << 7;
static constexpr uint16_t HKEY_STA = 1u << 8;
static constexpr uint16_t HKEY_SEL = 1u << 9;
static constexpr uint16_t HKEY_BL = 1u << 10;
static constexpr uint16_t HKEY_BR = 1u << 11;
static constexpr uint16_t HKEY_HOME = 1u << 12;

//-----------------------------------------------------------------------------
// WildCardBus
//-----------------------------------------------------------------------------
// LCIOn = GPIOn for n = 0..13. Which LCIO does what comes from the card
// profile (card_profile.hpp); only the LCD I2C pair is fixed by the spec.
static constexpr uint PIN_LCIO_BASE = 0;
static constexpr uint PIN_LC_LCD_SDA = 2;  // LCIO2 (I2C1 SDA)
static constexpr uint PIN_LC_LCD_SCL = 3;  // LCIO3 (I2C1 SCL)
// Virtual I/O expander bus (spec/02): the host is an i2c1 *slave* here.
// Mutually exclusive with the I2C LCD capture above (same controller).
static constexpr uint PIN_LCVIO_SDA = 6;  // LCIO6 (I2C1 SDA)
static constexpr uint PIN_LCVIO_SCL = 7;  // LCIO7 (I2C1 SCL)

// Logic card USB (PIO-USB host). DM must be DP + 1.
static constexpr uint PIN_LCUSB_DP = 30;
static constexpr uint PIN_LCUSB_DM = 31;

// PIO block assignment: pio0 = host LCD (8080), pio1 = PIO-USB host,
// pio2 = LcdTap SPI capture.
static constexpr uint PIO_USB_INDEX = 1;

// System clock (sys_clock.hpp). Peripheral dividers are derived from it.
// 312 MHz gives the LcdTap SPI capture more margin against the 62.5 MHz
// SCLK of PicoSystem cards (spi_4line_mode0.pio worst case = clk_sys / 4).
static constexpr uint32_t SYS_CLOCK_HZ = 312'000'000;

// TF card layout (see spec/05_tf_card.md).
static constexpr const char* CARDS_DIR = "/WCB/Cards";

}  // namespace wcb

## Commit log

2026-08-20 Add SPEC.md and pretest firmware for TJP card bring-up
    Pretest firmware for testing the TJP (TinyJoypad) logic card before the
    main firmware exists: detects the card by probing its ID EEPROM, resets
    the ATtiny85, forwards host keypad (PCA9555) presses to the card's
    open-drain key lines, and mirrors the card's SSD1306 I2C stream through
    LcdTap onto the host ILI9488 (own PIO+DMA 8080 8-bit driver, dirty-row
    partial updates). Debug output over USB CDC.
    [aux_i2c.cpp, board_pins.hpp, card_io.cpp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]
2026-08-21 Split AUX I2C into HAUX/LCAUX buses and debounce card detection
    Host keypad (PCA9555) moves to HAUX on GPIO36/37; the logic card EEPROM
    stays on LCAUX (GPIO28/29). Both pairs belong to I2C0, so the pad
    functions are switched per access and the idle pair is left Hi-Z, keeping
    card hot-plug glitches off the host bus. The new pair is attached before
    the old one is parked (a peripheral input with no GPIO reads Low, which
    the DW master took as a foreign START and went silent), the controller is
    re-initialized on every switch and after any failed transfer.
    Card detection now requires 3 consecutive EEPROM ACKs 200 ms apart,
    without blocking the main loop.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
    [aux_i2c.cpp, board_pins.hpp, main.cpp]
2026-08-21 Add TF card browser and ATtiny85 ISP programming to pretest
    System menu (HOME): Launch / Apps. Apps browses the TF card over SPI0
    with FatFs R0.16 (read-only, LFN, exFAT; vendored under firmware/lib/fatfs
    with an own SD SPI driver) starting at /WCB/Cards/TJP/Apps, and programs
    the selected .bin / Intel HEX image into the ATtiny85 over a bit-banged
    ISP on LCIO2/3/9/13 (signature check, chip erase, page write, verify).
    The I2C1 slave is suspended and all key lines released during
    programming; the new app starts on RESET release.
    LcdTap output scaling changed to FIT.
    [board_pins.hpp, card_io.cpp, isp_tiny85.cpp]
2026-08-21 LCTF_xxxx pin assign changed
2026-08-23 Read the card profile on detection and add profile writing to pretest
    Card detection now reads the profile EEPROM after the ACK debounce and
    validates length, CRC32 and the CBOR object (QCBOR, added as a submodule)
    before the card counts as present; invalid profiles show their reason
    and keep the Profile menu reachable. The WildCardBus is configured from
    the profile instead of TJP constants: key lines / RESET per port mode,
    key map, LcdTap preset + cfg overrides (I2C bus only), ISP pins, and the
    Apps directory /WCB/Cards/<id>/Apps.
    The system menu gains "Profile": browse /WCB/Cards for a .hex, expand it
    to SRAM (CBOR <= 4 KB), validate, confirm with id/name, write it to the
    EEPROM page-wise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
    [aux_i2c.cpp, board_pins.hpp, card_eeprom.cpp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]
2026-08-23 Support PicoPad (PP1/PP2) cards: SPI LcdTap, USB ISP, card stop/start
    - System clock 288 MHz; core 1 now runs the LcdTap capture (I2C or the
    4-line SPI PIO slave from lcdtap) plus the dirty scan and hands output
    line groups to core 0 through a lock-free queue.
    - Logic card has stopped/running states: RESET is held while stopped,
    LCTF_ENAX follows useTfCard while running (host SPI pins go Hi-Z). A
    card present at boot starts automatically; hot insertion and app
    programming end with a "Start card?" prompt. Menu: Start/Stop card.
    - USB ISP: Pico-PIO-USB (submodule) + TinyUSB dual-role (CDC stdio on the
    native port, MSC host on GPIO30/31). BOOTSEL+RESET sequence, UF2 blocks
    written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
    [board_pins.hpp, card_io.cpp, card_profile.cpp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]
2026-08-24 Add isp.mcu (ATmega32U4 SPI ISP) and EEPROM page-size auto-detection
    The card profile's new isp.mcu field selects the programming target: the
    editor gets an MCU selector with validation, and the SPI ISP is
    generalized from ATtiny85-only to an AVR device table (signature, flash
    and page size), adding ATmega32U4. An absent isp.mcu keeps meaning
    ATtiny85. App image buffer grows to 32 KB and size checks follow the
    selected device.
    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
2026-08-25 Add UART ISP (method 2) and virtual I/O expander specs; add ESPboy card
2026-08-25 pretest: ESPboy support (UART ISP, virtual MCP23017, SPI capture resync)
2026-08-26 Rename card IDs (ABY/PP1/PP2/TJP -> Arduboy/PicoPad1/PicoPad2/TinyJoyPad); add missing isp.mcu
    [main.cpp, profile_test.cpp]
2026-08-27 Add Xiamocon RP2350 card: PCA9555 virtual I/O expander, display-reset spec
    - spec/02-04: pca9555 chip for the virtual I/O expander (pair-toggling
    auto-increment, polarity inversion honored), virtual port f=1 = display
    reset (INPUT+neg, host support staged), keymap multi-source OR
    - cards/XiamoconRP: SPEC.md, profile.json/hex (shared LCD/TF SPI bus,
    PCA9555 @0x22, function switch on both bumpers, USB MSC ISP)
    - pretest: PCA9555 emulation in virt_ioexp (chip-dispatched IRQ handler),
    profile validation for pca9555 and the virtual display-reset port
    - profile-editor: pca9555 chip ID, LCD I/F on virtual ports, tests
    [card_profile.cpp, card_profile.hpp, main.cpp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]
2026-08-27 Name the main unit "host shell" in the specs
    The daughter board is the "logic card"; the main unit is now the
    "host shell" (defined in spec/00_overview.md). Replace 本体/本体側
    accordingly in spec/, the SPEC.md index and cards/XiamoconRP.
2026-08-29 Add PicoSystem card (on-card deserializer, 8bit parallel) and host support
    - spec: LCD VSYNC output feature (function 3 + top-level vsync member,
    host-generated PWM pulse); sync profile-editor UI/validation/tests
    - pretest: VSYNC PWM output, card debug UART on LCIO11 (uart1 RX -> CDC),
    312 MHz sysclk (more SPI-capture margin), 8-bit parallel LCD capture
    (lcdtap parallel_8bit.pio; profile bus check now allows PARALLEL)
    - cards/PicoSystem: 74HC595+74HC4040 deserializer topology on LCIO0-11,
    push-pull buttons (the PicoSystem SDK init_inputs pin-mask bug leaves
    its internal pull-ups disabled), VSYNC generation T.B.D. (on-card MCU),
    B0-silicon note (official builds panic on ROM v1)
    C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
    [board_pins.hpp, card_io.cpp, card_profile.cpp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]
2026-08-31 add KiCad project
    [host_shell.kicad_pcb, host_shell.kicad_sch]
2026-08-31 wip: schematics
    [host_shell.kicad_sch]
2026-09-02 schematic review feedback
    [host_shell.kicad_sch]
2026-09-04 add RTC
    [host_shell.kicad_pcb, host_shell.kicad_sch]
2026-09-07 layout review feeedback
    [host_shell.kicad_pcb, host_shell.kicad_sch]
2026-09-07 add silks
    [host_shell.kicad_pcb]
2026-09-07 fix L/R of speaker and bumper
    [host_shell.kicad_pcb, host_shell.kicad_sch]
2026-09-07 set LCD connector as DNP
    [host_shell.kicad_sch]
2026-09-08 fix logo
    [host_shell.kicad_pcb]
2026-09-08 fix footprint
    [host_shell.kicad_pcb, host_shell.kicad_sch]
2026-09-08 rev.1 PCBA ordered
    [host_shell.kicad_pcb]
2026-09-10 add gfx3d prototype
2026-09-11 gfx3d: add pretest example, fixed-point rasterizer
    - example/pretest: run the demo scene on the pretest host shell (band
    rendering with async LCD DMA, keypad camera, per-stage timing overlay)
    - example/common: scene shared by the WASM and pretest examples
    - lib: integer pixel loops specialized per blend/texture/flat, spans as
    value + per-pixel delta (no per-pixel float, no divisions in span
    setup), x-sorted opaque span list + separate translucent list, line
    buckets + active triangle list, index sort, vertex cache
    - textures must now be power-of-two sized
    RP2350 (312 MHz, single core): render 51-58 ms -> 14-18 ms, 15-18 fps -> 40-46 fps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
    [lcd_ili9488.cpp, main.cpp]
